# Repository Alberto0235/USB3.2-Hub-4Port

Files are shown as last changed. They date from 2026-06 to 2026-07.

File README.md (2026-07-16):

<h1 align="center">⚡ USB 3.2 Gen 1 — 4-Port Hub</h1>

<p align="center">
High-Speed Hardware Design
</p>

<p align="center">
  
  
  
  
</p>

<p align="center">
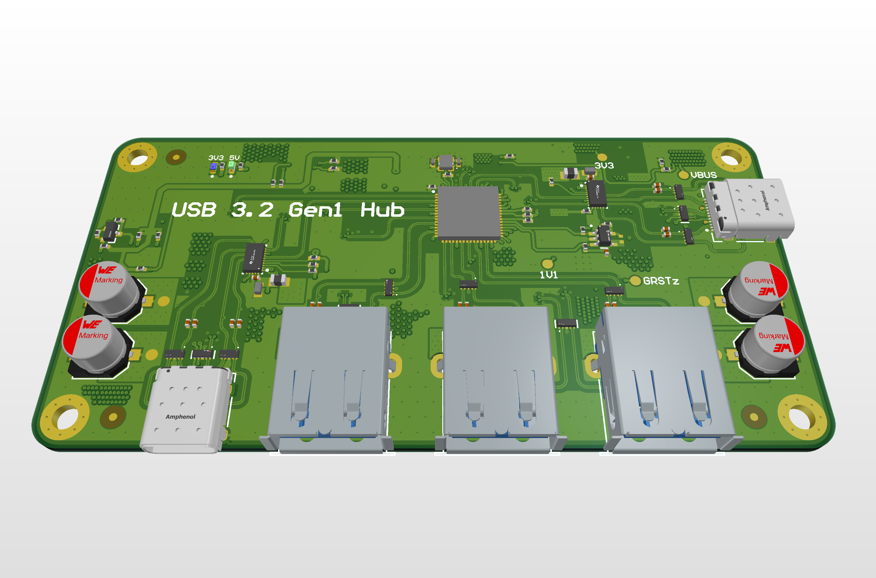
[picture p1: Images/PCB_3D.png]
  
</p>

<p align="center">
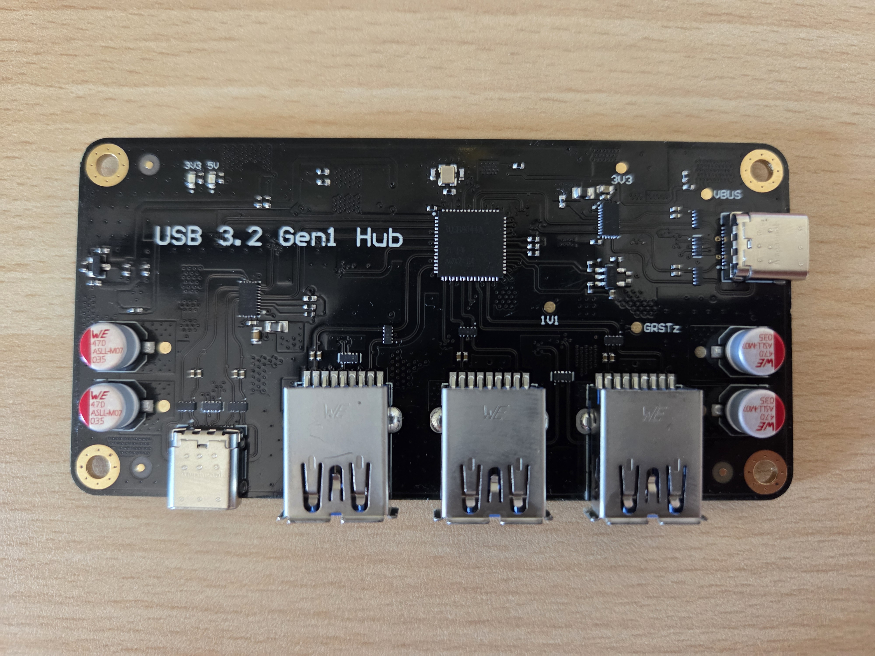
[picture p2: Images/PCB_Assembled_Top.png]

</p>

---

## 🎯 Project Goal

This project started as a question: could I take a commercial-grade USB 3.x system from architecture all the way through to a manufacturable, impedance-controlled 6-layer PCB?

The hub is built around the Texas Instruments **TUSB8044A**, fully bus-powered over USB-C, with one USB-C downstream port (cold-socket compliant) and three USB-A ports, each with independent current limiting. Type-C attach detection, power-up sequencing and overcurrent handling are implemented entirely in hardware, with no microcontroller required.

The areas I specifically wanted to get right:

- Routing 5 Gbps SuperSpeed differential pairs with impedance control
- Understanding the 6-layer stackup advantages
- Implementing USB-C cold socket behavior correctly, in hardware, per spec
- Getting power-up sequencing timing right against the TUSB8044A's datasheet requirements

---

## 🚀 Project Status

- [x] Architecture & component selection
- [x] Schematic capture (hierarchical, multi-sheet)
- [x] Signal integrity analysis & stackup design
- [x] PCB layout & routing
- [x] Manufacturing files (Gerbers, BOM, Pick & Place)
- [x] DFM review (PCBWay)
- [x] PCB fabrication & assembly
- [x] Bring-up & validation

---

## 🧩 Board Features

| Feature | Description |
|---|---|
| ⚡ USB 3.2 Gen 1 | 5 Gbps SuperSpeed, 4-port hub (TUSB8044A) |
| 🔌 USB-C UFP | Bus-powered upstream, 5V/3A max |
| 🧊 Cold Socket | Hardware VBUS gating on USB-C downstream port |
| 🔋 BC1.2 CDP | Charging support on all downstream ports |
| 🛡️ ESD Protection | All USB data lines, CC lines, and VBUS protected |
| 📡 Controlled Impedance | 90Ω differential SS/HS routing, 6-layer stackup |
| 🔄 Power Sequencing | Hardware-controlled, RC-delayed reset |
| 🧠 No MCU | All Type-C and power logic implemented in hardware |

---

## 🏆 Engineering Highlights

### 📡 Signal Integrity — 90Ω Differential Impedance

All SuperSpeed and High-Speed differential pairs are routed exclusively on **L1 and L6**, each directly referenced to a solid, unbroken GND plane (L2 and L5). Routing follows the 5W rule, a minimum of 0.6mm clearance between any differential pair and other signals or copper pour, preventing nearby copper from acting as a parasitic coplanar ground and shifting the impedance off target.

| Parameter | SuperSpeed (USB 3.x) | High-Speed (USB 2.0) |
|---|---|---|
| Target differential impedance | 90Ω ±10% | 90Ω ±10% |
| Intra-pair skew | ≤ 0.15mm (≈1.2ps) | ≤ 3.8mm |
| Max via count per pair | 2 | 4 |
| AC coupling | 100nF, 0402, X7R — TX paths only | — |

<p align="center">
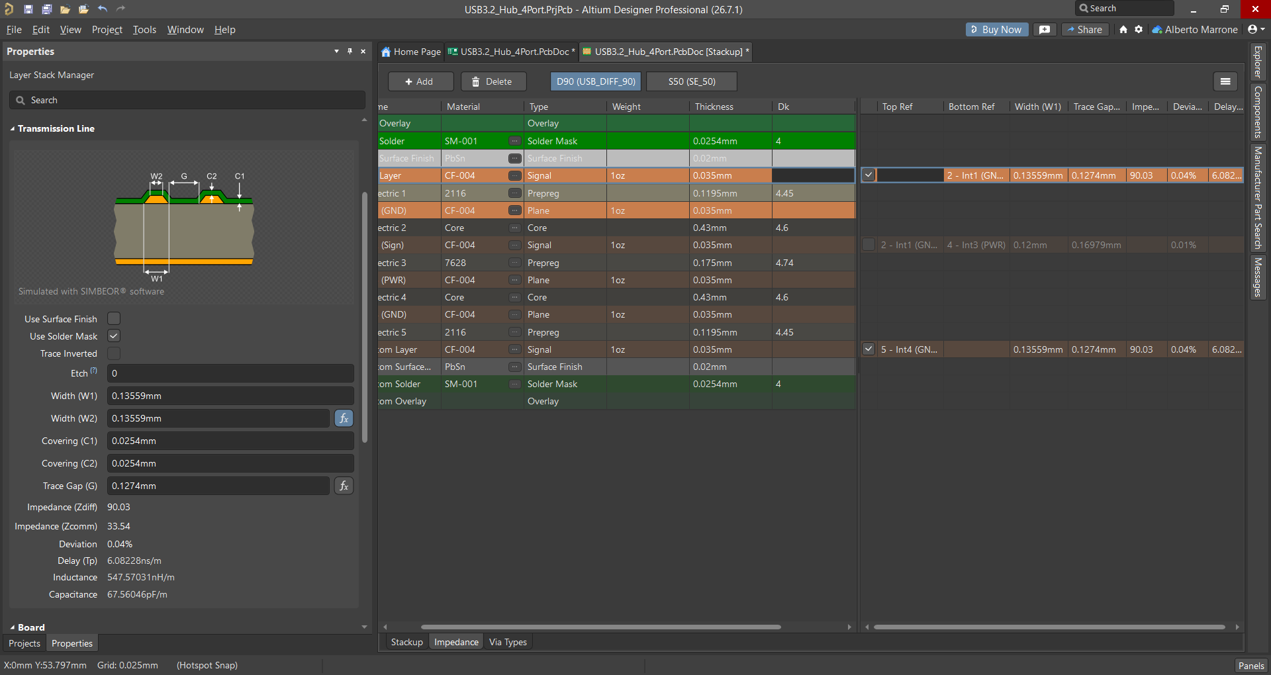
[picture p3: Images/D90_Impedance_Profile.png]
  
</p>

> [!TIP]
> Both the TUSB8044A and HD3SS3220 support **native polarity inversion** on
> SuperSpeed pairs — P/N can be swapped freely during routing with no via
> tricks or register configuration required.

---

### 🧱 6-Layer Stackup Selection

| Layer | Type | Function |
|---|---|---|
| L1 | Signal | High-speed routing & components |
| L2 | GND Plane | Solid reference |
| L3 | Signal | Low-speed control signals |
| L4 | Power Plane | 5V / 3.3V / 1.1V |
| L5 | GND Plane | Solid reference |
| L6 | Signal | High-speed routing & components |

Both signal layers carrying HighSpeed and SuperSpeed traffic (L1 and L6) sit directly against a solid GND plane. Slow control signals are confined to L3, sandwiched between a GND plane (L2) and the power plane (L4), shielding them from both the high-speed layers and external noise.

> [!NOTE]
> The prepreg between L1–L2 and L5–L6 uses **2116 weave** instead of the
> coarser 7628. The finer glass weave reduces the fiber-weave effect,
> keeping the dielectric more homogeneous under the SuperSpeed pairs and
> minimizing intra-pair skew. Full reasoning, including why 6 layers over
> 4, and why an LDO over a second buck for the 1.1V rail, is documented in
> [`Docs/Design_Decisions.md`](Docs/Design_Decisions.md).

---

### 🔌 USB-C Cold Socket Compliance

Per the USB Type-C specification, the downstream USB-C port's VBUS must remain de-energized until a cable is detected, unlike USB-A ports, which are permitted to be hot-socket. This is implemented with a single P-MOSFET acting as a hardware enable gate, requiring no firmware:

- **Source** → PWRCTL1 (TUSB8044A, 3.3V when hub is active)
- **Gate** → ID pin of the downstream HD3SS3220
- **Drain** → EN1 of the TPS2561 power switch

With no cable inserted, the ID pin floats and a 100kΩ gate-source resistor holds the MOSFET off, VBUS stays at 0V. On attach, the HD3SS3220 detects the termination on CC and pulls ID low, turning on the MOSFET and enabling VBUS. The three USB-A ports use direct PWRCTL → EN connections, as hot-socket behavior is permitted there.

---

### 🔋 Power Budget

The hub negotiates 3A from the upstream USB-C port. Hub control circuitry and always-on rails consume a portion of this budget, leaving the remainder for the four downstream ports.

| Item | Current |
|---|---|
| Upstream budget (USB-C UFP) | 3000 mA |
| Hub controller + support circuitry | ≈ 582 mA |
| Available for downstream ports | ≈ 2418 mA |
| Ports 1–2 limit (TPS2561 #1, R_ILIM = 37.4kΩ) | 1.5 A each |
| Ports 3–4 limit (TPS2561 #2, R_ILIM = 56kΩ) | 1.0 A each |
| Sum of all port limits (worst case, all ports active) | 5.0 A |

> [!NOTE]
> The sum of individual port limits (5A) exceeds the available downstream
> budget (2.418A). This is an accepted worst-case scenario: simultaneous
> maximum draw on all four ports is unlikely in practice, and the upstream
> host's own port protection provides a final safeguard if the negotiated
> 3A is exceeded.

---

### ⏱️ Power Sequencing

> [!IMPORTANT]
> The TUSB8044A requires GRSTz to remain asserted for ≥3ms after both VDD
> (1.1V and 3.3V) enter their recommended operating range.

| Event | Time |
|---|---|
| VBUS 5V applied | 0 ms |
| Buck PG asserted → LDO enabled | ≈ 0.5 ms |
| LDO soft-start complete (Css = 2.2nF, tSS ≈ 3.3ms) | ≈ 3.8 ms |
| LDO PG released → RC delay begins | ≈ 4.3 ms |
| GRSTz reaches V_IH → TUSB8044A exits reset | ≈ 16 ms |

The RC delay accounts for the TUSB8044A's internal pull-up on GRSTz (R_int ≈ 14.5–25kΩ): with an external 100kΩ resistor and a 1µF capacitor, R_eq ≈ 12.66kΩ. The time delay is comfortably above the 3ms minimum required after both supplies are stable.

> [!NOTE]
> The measured GRSTz de-assertion delay from VBUS rise to the logic-high threshold is **tGRSTz = 42.6 ms**
> This delay is dominated by the TUSB8044A internal reset release mechanism and the external reset network.
> The measured value confirms that GRSTz remains asserted long enough during power-up sequencing.
> The difference between the expected and measured timing is attributed to device tolerances,
> reset circuitry characteristics and measurement conditions.

<p align="center">
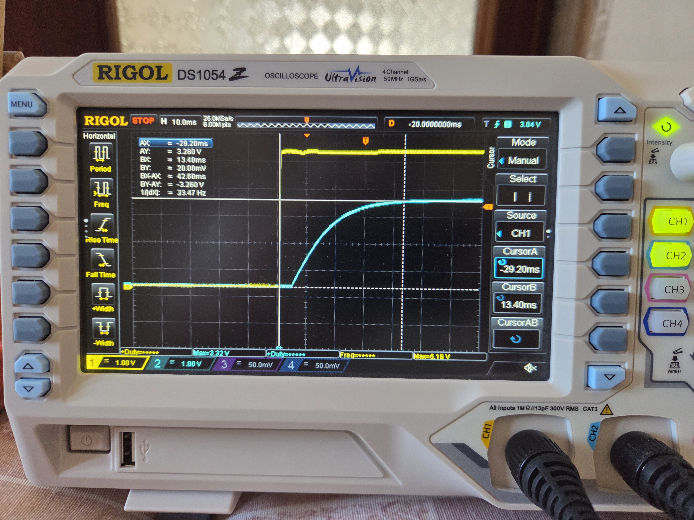
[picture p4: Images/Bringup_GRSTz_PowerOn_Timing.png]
  
</p>
<p align="center"><em>Channel 1 — VBUS 5V.  Channel 2 — GRSTz.  tGRSTz = 42.6 ms from power-on.</em></p>

---

## 🖼️ Design Gallery

### Final Prototype

<p align="center">
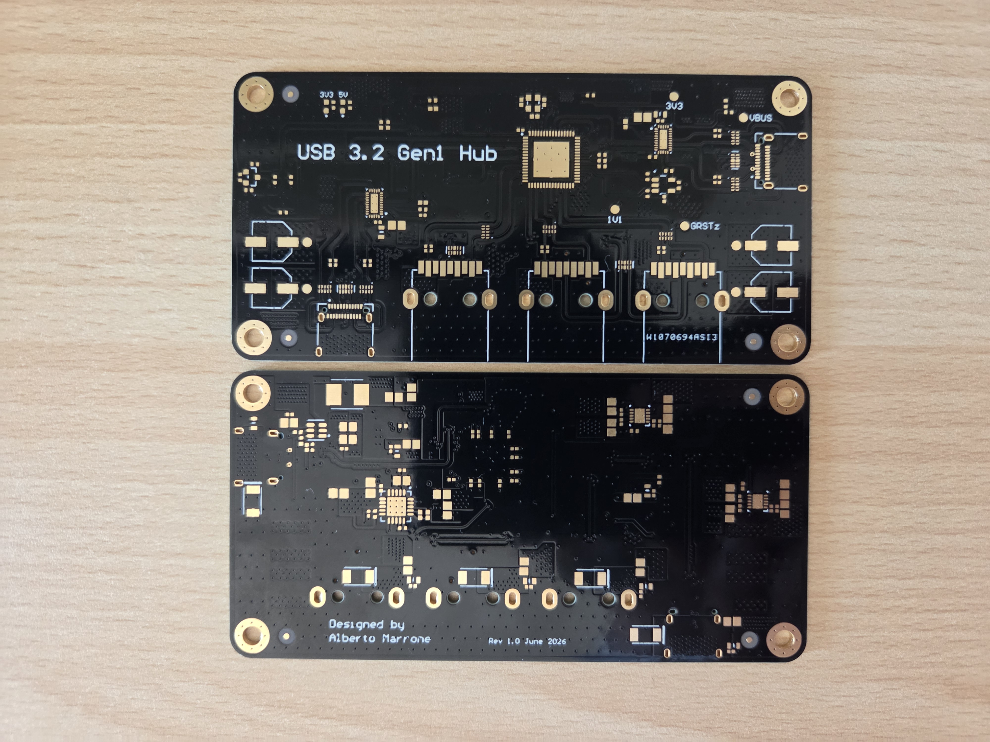
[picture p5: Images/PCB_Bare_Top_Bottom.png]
  
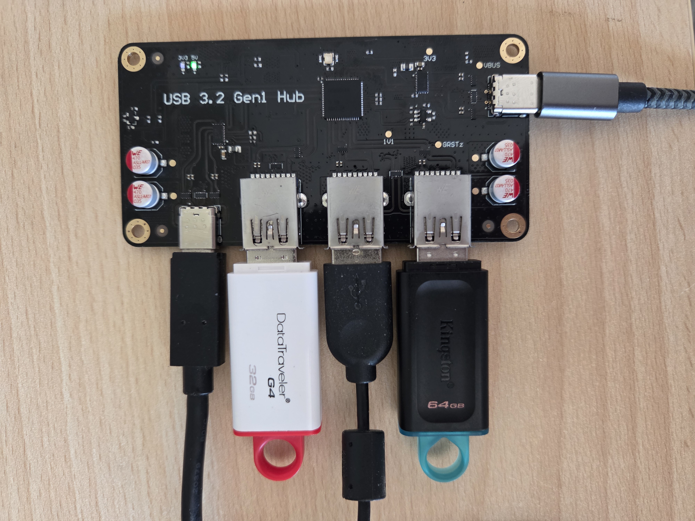
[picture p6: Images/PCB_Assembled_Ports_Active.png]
  
</p>

### PCB Render

<p align="center">
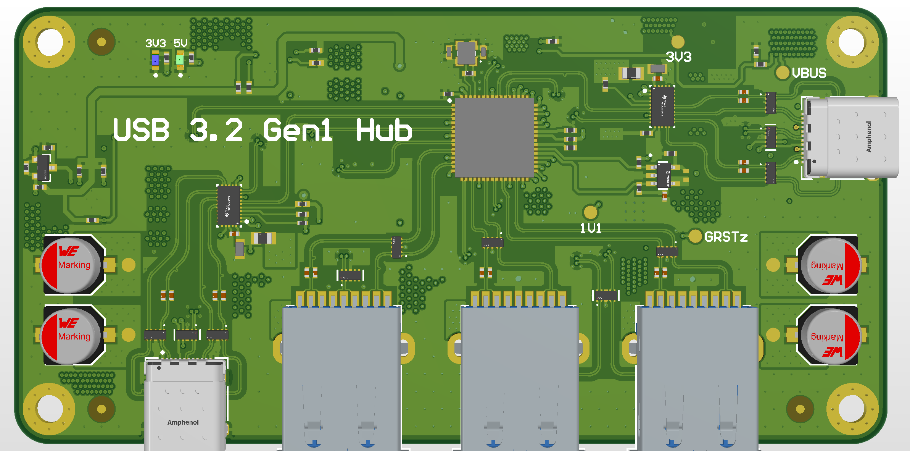
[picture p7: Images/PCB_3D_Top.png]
  
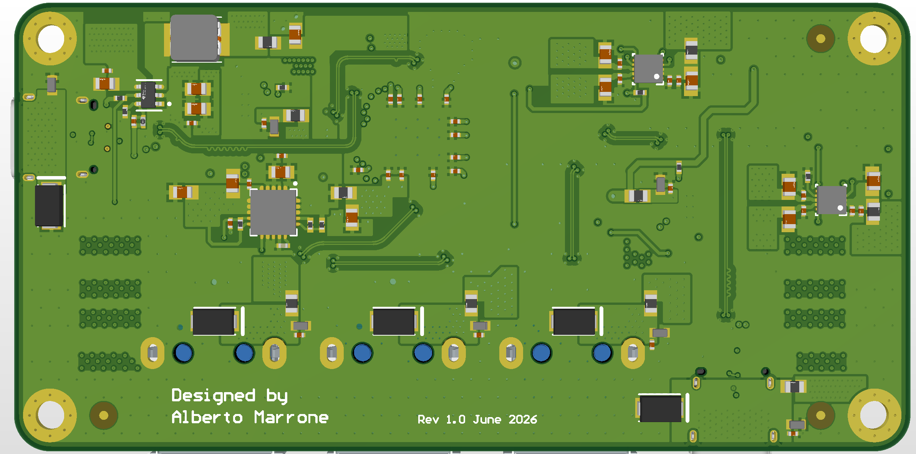
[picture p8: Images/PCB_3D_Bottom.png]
  
</p>

### Schematic Architecture

<p align="center">
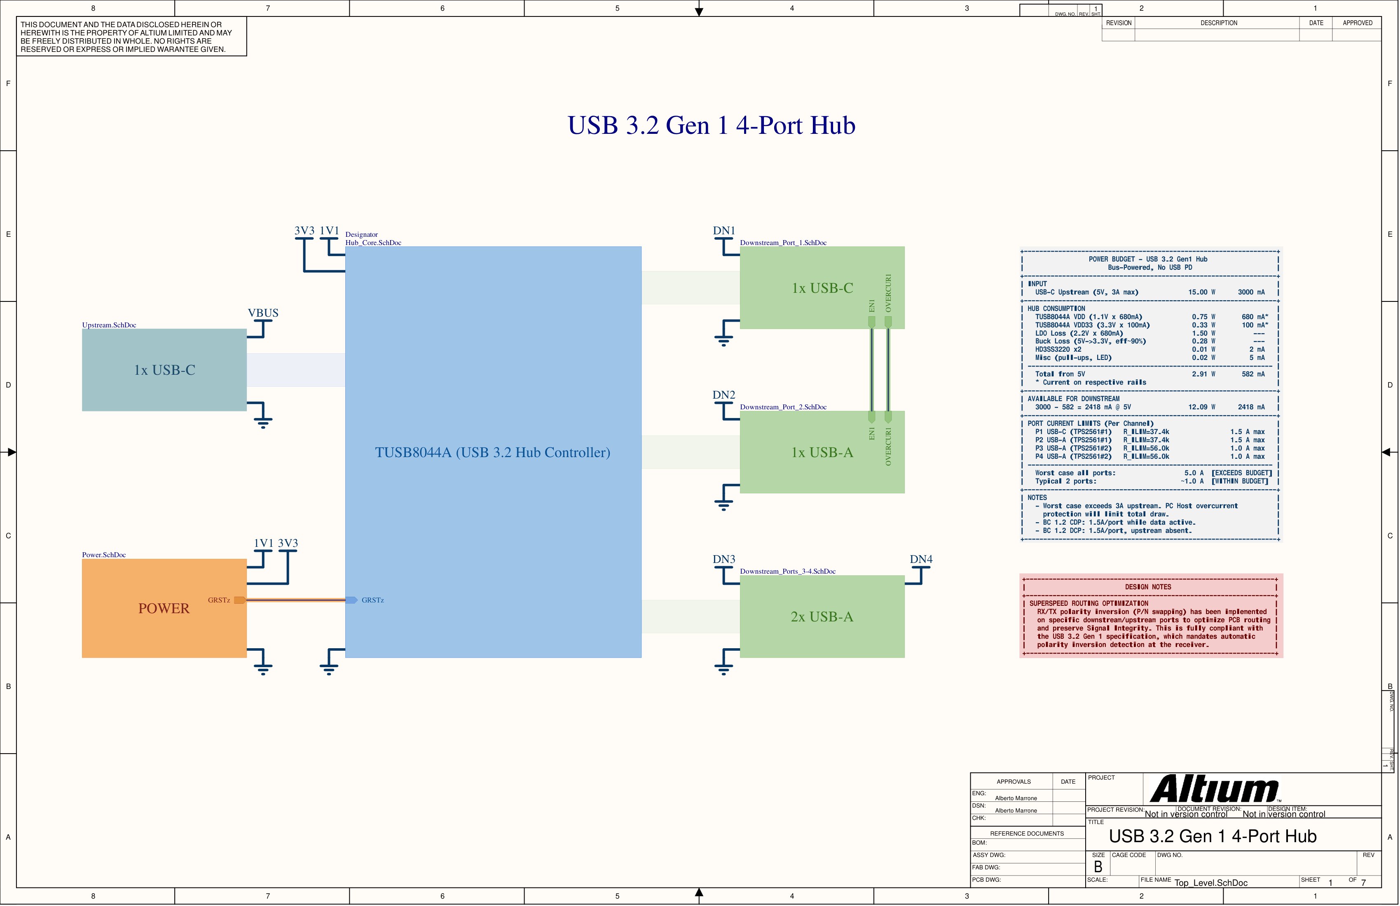
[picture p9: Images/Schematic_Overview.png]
  
</p>

🔗 **Full schematic (PDF, all sheets):** [Schematic_USB_Hub_v1.0.pdf](Hardware/Exports/Schematic_USB_Hub_v1.0.pdf)

### Stackup Development

<p align="center">
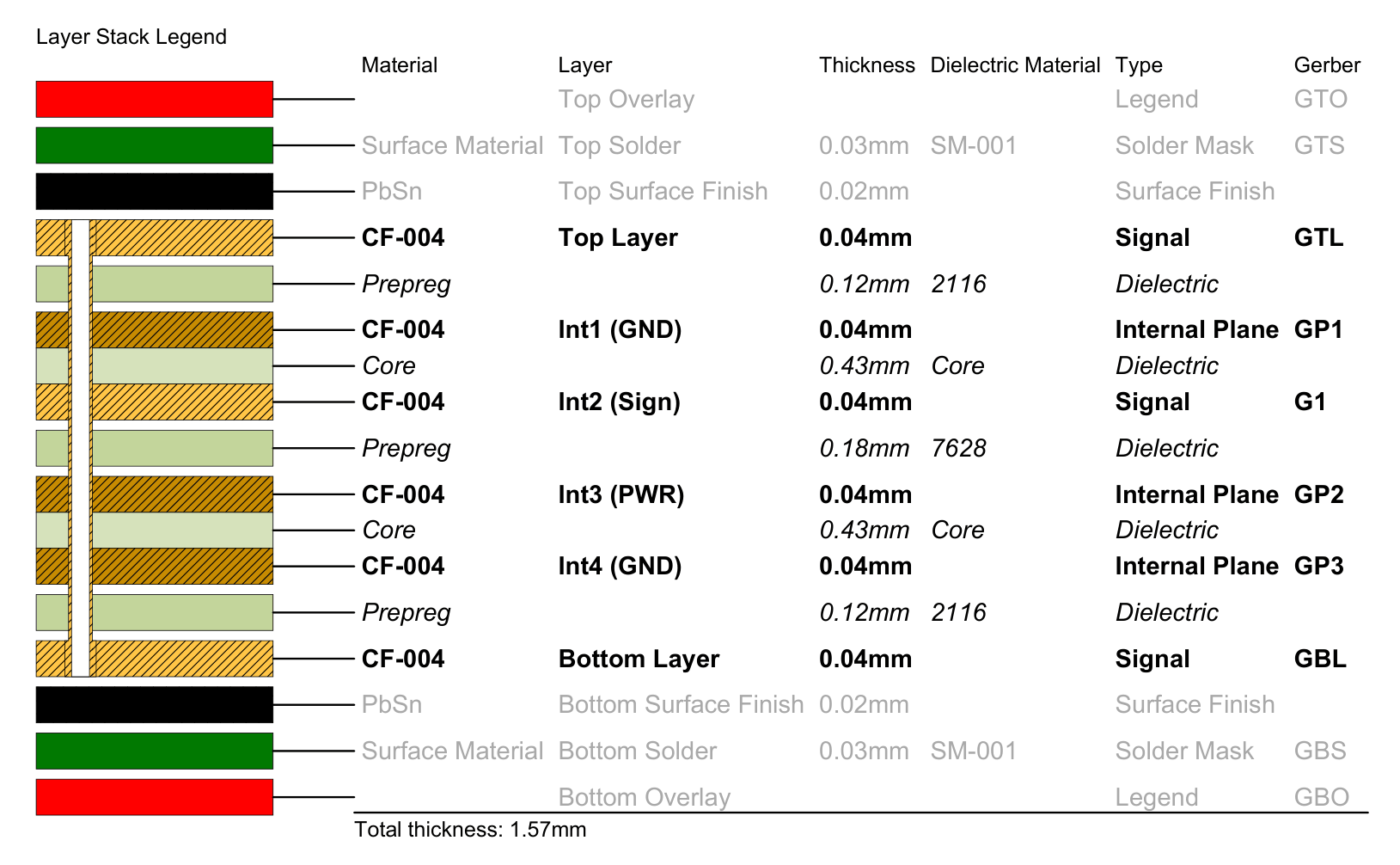
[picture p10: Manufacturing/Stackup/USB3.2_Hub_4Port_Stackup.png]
  
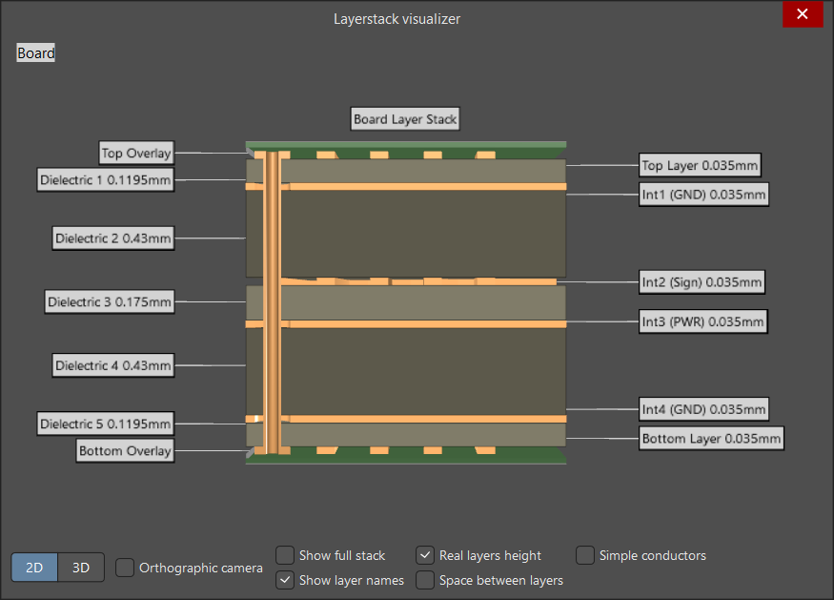
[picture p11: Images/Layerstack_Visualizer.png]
  
</p>

---

## 🔧 Hardware Specifications

| Parameter | Value |
|---|---|
| **Hub Controller** | TUSB8044A — USB 3.2 Gen 1, 5 Gbps, 64-pin VQFN |
| **Upstream Port** | USB-C (UFP/Sink, bus-powered, 5V/3A max) |
| **Downstream Ports** | 1× USB-C (DFP) + 3× USB-A |
| **Type-C Controllers** | 2× HD3SS3220IRNHT (UFP + DFP) |
| **Power Switches** | 2× TPS2561QDRCRQ1 (dual-channel, per-port current limiting) |
| **Power Tree** | 5V → 3.3V (TLV62569PDDCT buck, 2A) → 1.1V (TPS74801RGWRM3 LDO, 1.5A) |
| **Battery Charging** | BC 1.2 CDP enabled on all downstream ports |
| **Cold Socket** | DMG2305UX P-MOSFET on USB-C downstream port |
| **ESD Protection** | PUSB3FR4Z (SS), TPD4E05U06 (USB2.0/CC), SMAJ5.0A (VBUS) |
| **PCB Layers** | 6-layer, impedance-controlled |
| **PCB Finish** | ENIG (Electroless Nickel Immersion Gold) |
| **Copper Weight** | 1 oz outer / 0.5 oz inner |
| **Board Size** | 100 × 50 mm |

---

## 🤝 Manufacturing Partner

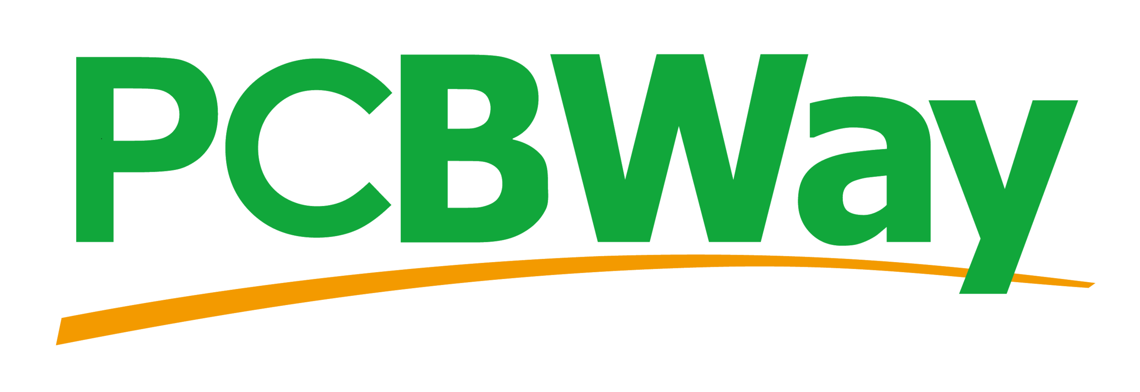
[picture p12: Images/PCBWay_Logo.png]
This prototype was fabricated and assembled by .

The manufacturing process included a standard engineering review prior to production. During this review, the PCBWay engineering team identified a via-in-pad condition that could affect assembly yield. The issue was corrected before fabrication, avoiding an unnecessary prototype revision.

The finished boards met the specified impedance-controlled stackup and assembly requirements. Visual inspection of the assembled prototype showed good component alignment and solder quality, including the 0.5 mm-pitch VQFN packages used by the TUSB8044A and HD3SS3220 devices, with no observable solder bridges or placement defects.

---

## ✅ Bring-Up Results

Validation was performed on the first prototype assembled by PCBWay.
Full procedure and raw measurements are documented in [`Docs/Bringup_Procedure.md`](Docs/Bringup_Procedure.md).

### Power Rails

All rails measured at test points with no downstream load.

| Rail | Target | Measured | Status |
|---|---|---|---|
| VBUS (upstream input) | 5.000 V | 5.018 V | ✅ |
| VDD33 | 3.300 V | 3.325 V | ✅ |
| VDD (1.1V LDO) | 1.100 V | 1.097 V | ✅ |
| GRSTz (at de-assertion) | — | 3.265 V | ✅ |
| VBUS downstream USB-A | 5.000 V | 5.018 V | ✅ |

Idle power consumption (hub only, no downstream devices): **0.02 A @ 5.041 V → 0.1 W.**

### USB Enumeration

Both logical hub interfaces enumerate correctly on the first attempt:

| Interface | PID | Speed | Status |
|---|---|---|---|
| USB 2.0 HS hub | 0x8442 | 480 Mbit/s | ✅ |
| USB 3.x SS hub | 0x8440 | 5 Gbit/s | ✅ |
| HID-to-I2C bridge | 0x82FF | HS | ✅ |

EEPROM custom USB descriptors were successfully programmed and verified after enumeration:

```text
Manufacturer : Alberto Marrone
Product      : USB 3.2 Gen1 4-Port Hub
Serial       : F10100616729  (TI factory UUID)
```

<p align="center">
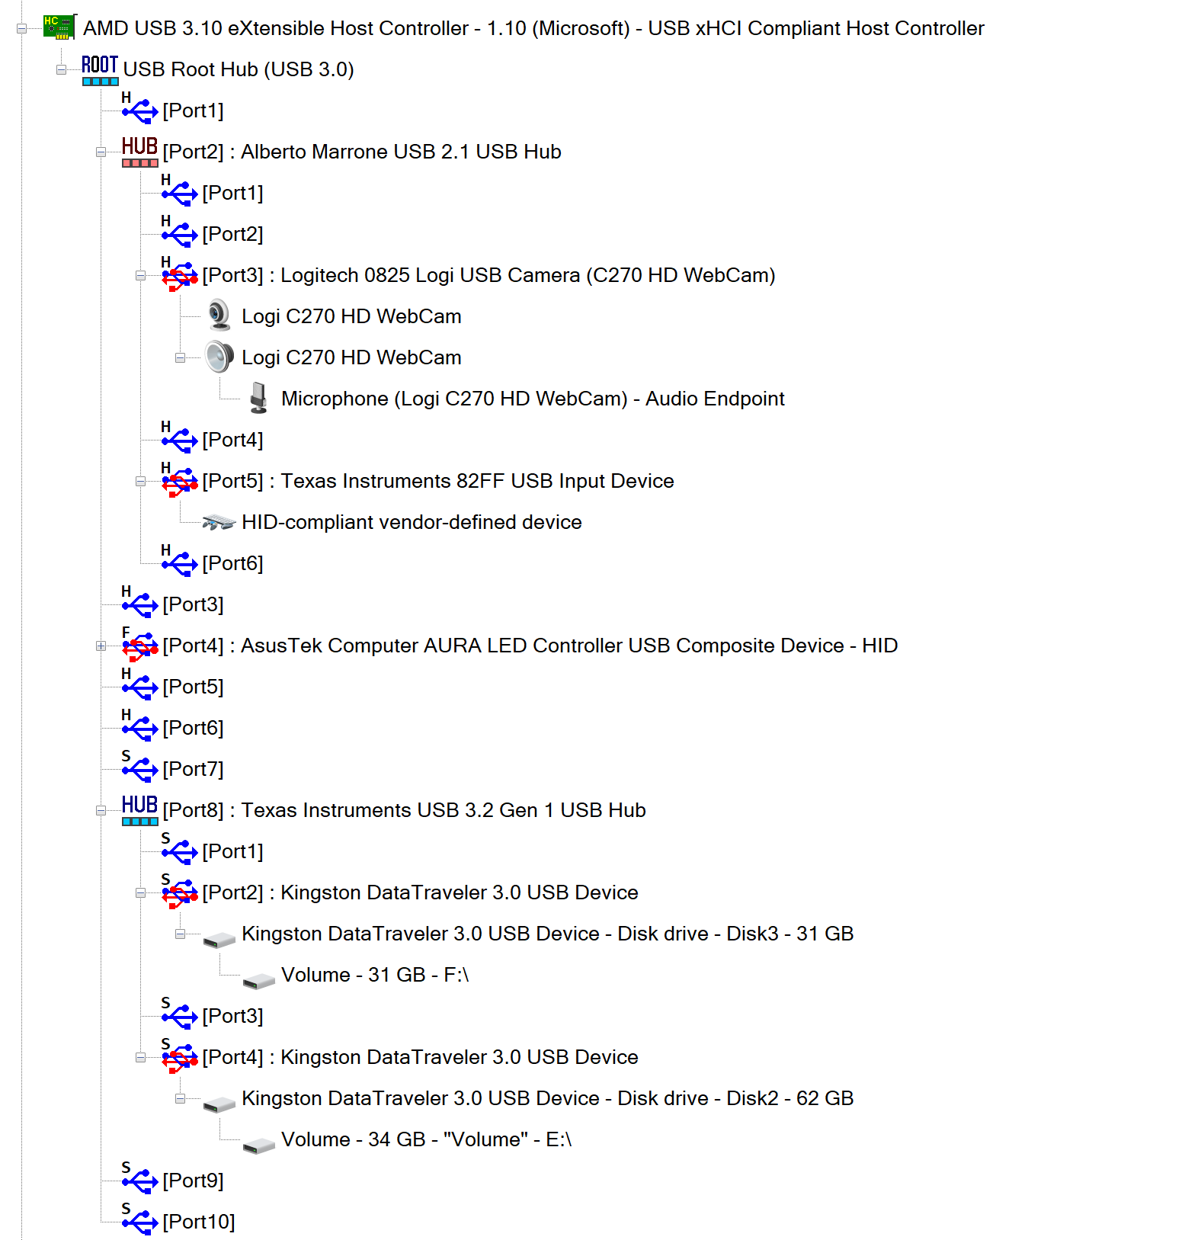
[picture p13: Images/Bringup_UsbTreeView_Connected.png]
  
</p>
<p align="center"><em>UsbTreeView — HS hub and SS hub.</em></p>

### SuperSpeed Performance

Validated using USBDeview's built-in Speed Test utility on a Kingston DataTraveler 3.0 device.

<p align="center">
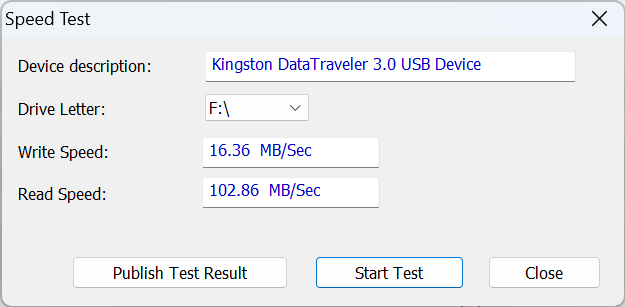
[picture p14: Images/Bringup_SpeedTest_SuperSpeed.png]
  
</p>

Read throughput of 102 MB/s is incompatible with USB 2.0 High-Speed (theoretical max ≈ 40 MB/s), confirming the SuperSpeed (5 Gbit/s) link is established end-to-end.

### Other Tests

- [x] Visual inspection (0.5 mm-pitch QFN solder joints, connectors)
- [x] GRSTz power-on timing (42.6 ms — see [Power Sequencing](#%EF%B8%8F-power-sequencing))
- [x] Per-port functional test — all 4 ports enumeration confirmed
- [x] USB 2.0 device compatibility
- [x] USB 3.0 device compatibility
- [x] Hot-plug on all four ports
- [x] USB-C cold socket — VBUS held at 0 V until cable attach confirmed
- [x] BC1.2 CDP charging verified

> [!NOTE]
> During continuous operation with multiple downstream devices connected, the TUSB8044A hub controller and the HD3SS3220
> controller run warm to the touch. Adding small heatsinks or improving airflow is recommended for prolonged high-load operation.

---

## 🔧 EEPROM Configuration

The TUSB8044A reads a Microchip **24LC08BT-I/OT** EEPROM (8 Kbit, SOT-23) at power-up to load
custom USB descriptors and port configuration. Programming is performed via the chip's internal
**HID-to-I2C bridge** (VID `0x0451`, PID `0x82FF`) — no external programmer required.

Two Python utilities are provided in [`Scripts`](Scripts/):

| Script | Purpose |
|---|---|
| `TUSB8044A_EEPROM_WRITE.py` | Writes the full configuration and verifies every byte before activating |
| `TUSB8044A_EEPROM_READ.py` | Reads all 1024 bytes, prints a register-annotated hex dump, saves a `.bin` |

### Requirements

```bash
pip install hidapi
```

On Windows, run CMD as **Administrator** (required for raw HID access).

### Write — program the hub

Edit the `USER CONFIGURATION` block at the top of `TUSB8044A_EEPROM_WRITE.py`:

```python
MANUFACTURER = "Alberto Marrone"          # manufacturer string (max 32 chars)
PRODUCT      = "USB 3.2 Gen1 4-Port Hub"  # product string (max 32 chars)

VID_HUB      = 0x0451                     # keep TI VID for prototypes
PID_HUB      = 0x8440                     # TUSB8044A SS hub PID

BC12_MASK    = 0x0F                       # BC1.2 CDP enable mask (0x0F = all 4 ports)
```

Then run:

```bash
python TUSB8044A_EEPROM_WRITE.py
```

The 0x55 signature byte that activates the configuration is written only after all registers and strings have been verified. If interrupted, the hub safely falls back to TI factory defaults.

### Read — dump and inspect the EEPROM

```bash
python TUSB8044A_EEPROM_READ.py
```

Outputs a hex dump of Bank 0 (configuration registers + strings), annotates every key
register, decodes the manufacturer/product strings, and saves the full 1024-byte image
to `TUSB8044A_EEPROM.bin` in the working directory.

### Recovery

If the hub shows **"Unknown USB Device"** after a failed write: short EEPROM U6 **pin 3 (SDA)
to pin 2 (GND)** while inserting the USB cable. The TUSB8044A I2C read times out, the hub
boots from TI factory defaults, and the write utility can be re-run.

---

## 📚 Lessons Learned

This project provided practical experience beyond schematic capture and PCB layout, particularly in areas that are rarely covered in university courses:

- Designing and routing a 6-layer controlled-impedance PCB for 5 Gbit/s differential routing.
- Translating impedance targets into manufacturable trace geometries using field-solver calculations.
- Understanding USB Type-C electrical requirements, including cold-socket behavior implemented entirely in hardware.
- Designing reliable power sequencing while accounting for internal IC behavior (such as GRSTz pull-up tolerance), not only the external RC network.
- Developing EEPROM programming and recovery tools through the TUSB8044A HID-to-I²C interface.
- Working through a real manufacturing DFM review with the PCB manufacturer before fabrication.
- Validating the completed hardware through electrical measurements, USB enumeration, and functional testing.

---

## ⬇️ Downloads

| File | Description |
|---|---|
| [Schematic (PDF)](Hardware/Exports/Schematic_USB_Hub_v1.0.pdf) | Full schematic, all sheets |
| [Draftsman Export (PDF)](Hardware/Exports/Draftsman_USB_Hub_v1.0.pdf) | Stackup, layers, 3D views |
| [Gerbers](Manufacturing/Gerbers/Gerber_USB3.2_Hub_4Port_v1.0.zip) | Production-ready Gerber + drill files |
| [BOM](Manufacturing/Assembly/BOM.xlsx) | Bill of materials |
| [Pick & Place](Manufacturing/Assembly/PickPlace.csv) | Assembly placement file |
| [PCBWay Stackup Reference (PDF)](Manufacturing/Stackup/PCBWay_6Layer_Stackup.pdf) | Manufacturer stackup |
| [EEPROM Write Tool](Scripts/TUSB8044A_EEPROM_WRITE.py) | Programs custom USB descriptor strings via HID-to-I2C |
| [EEPROM Read Tool](Scripts/TUSB8044A_EEPROM_READ.py) | Dumps and annotates full EEPROM contents |

---

## 📁 Repository Structure

```text
USB3.2-Hub-4Port/
│
├── Hardware/
│   ├── Altium/
│   │   ├── USB3.2_Hub_4Port.PrjPcb
│   │   ├── USB3.2_Hub_4Port.PcbDoc
│   │   ├── Top_Level.SchDoc
│   │   ├── Hub_Core.SchDoc
│   │   ├── Power.SchDoc
│   │   ├── Upstream.SchDoc
│   │   ├── Downstream_Port_1.SchDoc
│   │   ├── Downstream_Port_2.SchDoc
│   │   ├── Downstream_Port_3-4.SchDoc
│   │   ├── Outputs.OutJob
│   │   ├── USB3.2_Hub_4Port.BomDoc
│   │   ├── USB3.2_Hub_4Port.PCBDwf
│   │   ├── USB3.2_Hub_4Port.PrjPcbVariants
│   │   └── USB3.2_Hub_4Port.PrjPcbStructure
│   │
│   ├── Libraries/
│   │   ├── USB3.2_Hub_4Port.PcbLib
│   │   └── USB3.2_Hub_4Port.SCHLIB
│   │
│   └── Exports/
│       ├── Schematic_USB_Hub_v1.0.pdf
│       └── Draftsman_USB_Hub_v1.0.pdf
│
├── Manufacturing/
│   ├── Gerbers/
│   │   └── Gerber_USB3.2_Hub_4Port_v1.0.zip
│   │
│   ├── Assembly/
│   │   ├── BOM.xlsx
│   │   └── PickPlace.csv
│   │
│   └── Stackup/
│       ├── PCBWay_6Layer_Stackup.pdf
│       └── USB3.2_Hub_4Port_Stackup.png
│
├── Scripts/
│   ├── TUSB8044A_EEPROM_WRITE.py
│   └── TUSB8044A_EEPROM_READ.py
│
├── Docs/
│   ├── Design_Decisions.md
│   └── Bringup_Procedure.md
│
├── Images/               # PCB renders, prototype photos and bring-up measurements
│
└── README.md
```

---

## 📄 License

Released under the MIT License.

You are welcome to study, modify, manufacture, and build upon this design.

---

## 👤 Author

**Alberto Marrone**
MSc Student, Electronics Engineering — Politecnico di Milano
[LinkedIn](https://linkedin.com/in/alberto-marrone-444192274)

*This project is provided for educational and portfolio purposes.*

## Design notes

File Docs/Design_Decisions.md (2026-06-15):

# Design Decisions

## Why a 6-Layer Stackup

The primary design goal was maintaining controlled impedance and continuous return paths for all USB 3.2 Gen 1 SuperSpeed signals.

A conventional 4-layer stackup (Signal / GND / Power / Signal) would force one of the two outer signal layers to reference the power plane. Since the design contains multiple voltage domains (5V, 3.3V, and 1.1V), the power plane requires splits and polygon boundaries that can interrupt high-frequency return currents.

The selected 6-layer stackup allows both outer signal layers to reference solid, uninterrupted ground planes:

* L1 → referenced to L2 (GND)
* L6 → referenced to L5 (GND)

This guarantees a continuous return path for all SuperSpeed and High-Speed USB signals regardless of routing location.

Additional benefits include:

* Improved EMI performance
* Easier impedance control
* Better isolation between high-speed and low-speed signals
* Dedicated internal power distribution layer
* Easier routing

The final stackup is:

| Layer | Function |
| ----- | --- |
| L1 | High-speed signals & components |
| L2 | Solid GND plane |
| L3 | Low-speed control signals |
| L4 | Power distribution |
| L5 | Solid GND plane |
| L6 | High-speed signals & components |

---

## Why 2116 Prepreg for the Outer High-Speed Layers

The impedance-controlled USB pairs are routed exclusively on the outer layers (L1 and L6).

Between these layers the 2116 prepreg was selected instead of the coarser 7628 weave.

Compared to 7628, 2116 provides:

* A more homogeneous dielectric environment
* Reduced fiber-weave induced skew
* Thinner dielectric spacing
* More practical trace geometries for USB routing

The thinner dielectric also reduces the trace width required to achieve 90Ω differential impedance.

Using the selected stackup:

* Dielectric thickness = 0.12mm
* Differential impedance target = 90Ω
* Resulting geometry for the Diff pairs = 0.136mm trace width / 0.127mm gap

These dimensions allow straightforward breakout from the TUSB8044A and HD3SS3220 without excessive layer transitions.

The internal dielectric layers continue to use standard materials where signal integrity requirements are less critical.

---

## Why an LDO for the 1.1V Core Rail

The TUSB8044A requires a dedicated 1.1V rail for its internal core and PLL circuitry.

Two approaches were evaluated:

1. Secondary buck converter
2. Linear regulator

A buck converter would improve efficiency but introduce switching ripple and high-frequency noise directly onto the PLL supply.

The selected TPS74801 LDO provides:

* Low output noise
* High PSRR
* Simplified sequencing
* Reduced risk of PLL-related stability issues

Thermal analysis showed the additional dissipation remains acceptable within the expected operating conditions.

This approach is also consistent with Texas Instruments reference implementations for the TUSB8044A family.

---

## Why HD3SS3220 for USB-C Control

The TUSB8044A manages the USB hub functionality but does not provide USB Type-C attach detection or SuperSpeed orientation management.

The HD3SS3220 was selected because it combines:

* USB Type-C CC controller
* Orientation detection
* SuperSpeed lane switching
* Current advertisement logic

This keeps the design fully hardware-controlled while maintaining compliance with USB Type-C requirements.

---

## Why USB-C Cold Socket Implementation

USB Type-C ports must not present VBUS until a valid attachment has been detected through the CC pins. To satisfy this requirement, the downstream USB-C port uses a hardware-controlled enable path:

HD3SS3220 → PMOS → TPS2561 Enable

When no cable is present:

* CC detection remains inactive
* The PMOS remains off
* VBUS is disconnected

Once a valid attachment is detected:

* The HD3SS3220 asserts its ID output
* The PMOS turns on
* The TPS2561 power switch is enabled
* VBUS becomes available at the connector

No firmware is required.

The three USB-A ports remain permanently powered because USB-A connectors are allowed to operate as hot-socket ports.

---

## Why Copper Clearance Matters

High-speed differential pairs were routed with a minimum clearance of approximately 0.6mm from surrounding copper features. The objective is to prevent nearby copper from acting as an unintended coplanar reference plane and avoid crosstalk.

If copper is placed too close to a microstrip pair:

* Effective impedance decreases
* Field distribution changes
* Differential impedance may deviate from the target value
* Crosstalk

The selected clearance follows the 5W guideline and keeps impedance variation negligible compared to manufacturing tolerances. This spacing was applied consistently around all HighSpeed and SuperSpeed differential pairs throughout the design.

---

## Why a Hardware-Only Architecture

A design goal from the beginning was eliminating unnecessary firmware. Functions often delegated to a microcontroller are instead handled through dedicated hardware:

* USB-C attach detection
* Orientation detection
* Power sequencing
* Current limiting
* Overcurrent reporting
* Reset timing

Advantages include:

* Reduced system complexity
* Faster startup
* No firmware maintenance
* Lower validation effort
* Fewer failure modes

The final design contains no MCU and requires no software for normal operation.

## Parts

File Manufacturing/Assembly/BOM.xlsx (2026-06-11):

Name | Description | Designator | Quantity | Manufacturer 1 | Manufacturer Part Number 1 | Supplier 1 | Supplier Part Number 1 | Footprint
GRM21BZ71E106KE15L | Chip Multilayer Ceramic Capacitors for General Purpose, 0805, 10uF, X7R, 15%, 10%, 25V | C1, C11, C13, C14, C16, C24, C63, C65, C76, C78 | 10 | Murata | GRM21BZ71E106KE15L | Arrow Electronics | GRM21BZ71E106KE15L | FP-GRM21B-0_2-e0_2_0_7-IPC_B
GRT155R71H104KE01J | Multi-Layer Ceramic Capacitor 100nF 50V X7R ±10% 0402 Paper T/R | C2, C3, C4, C5, C6, C7, C8, C9, C12, C15, C17, C18, C19, C20, C23, C25, C30, C32, C33, C34, C35, C36, C39, C41, C43, C44, C46, C47, C48, C49, C51, C52, C53, C55, C56, C57, C59, C60, C64, C66, C68, C69, C70, C72, C73, C77, C79 | 47 | Murata | GRT155R71H104KE01J | Mouser | 81-GRT155R71H104KE1J | FP-GRT155-0_05-IPC_C
GCM1555C1H6R8BA16J | Ceramic Capacitor for Automotive 6.8pF ±0.1pF 50VDC C0G 0402 Paper T/R | C10 | 1 | Murata | GCM1555C1H6R8BA16J | Mouser | 81-GCM1555C1H6R8BA6J | FP-GCM155-0_05-IPC_B
GRM21BZ7YA475KE15K | Chip Multilayer Ceramic Capacitors for General Purpose, 0805, 4.7uF, X7R, 15%, 10%, 35V | C21, C22, C58, C71 | 4 | Murata | GRM21BZ7YA475KE15K | Newark | GRM21BZ7YA475KE15K | FP-GRM21B-0_2-e0_2_0_7-IPC_A
AC0402KRX7R9BB222 | CAP CER 2200PF 50V X7R 0402 | C26 | 1 | Yageo Group | AC0402KRX7R9BB222 | DigiKey | 311-3072-1-ND | FP-AC0402-0_5-MFG
GRM155Z71A105KE01D | Chip Multilayer Ceramic Capacitors for General Purpose, 0402, 1.0uF, X7R, 15%, 10%, 10V | C27 | 1 | Murata | GRM155Z71A105KE01D | Mouser | 81-GRM155Z71A105KE1D | FP-GRM155-0_1-IPC_C
1u | The superior mechanical strength and reliability due to the monolithic structure. Low ESR, ESL and excellent frequency characteristics allow for a circuit design that closely conforms to theoretical values. Low self-heating and high ripple resistance due to low ESR. No polarity | C28, C29, C31, C40, C42, C45, C50, C54, C67 | 9 | TDK | C1608X7R1H105K080AB | Mouser | 810-C1608X7R1H105K08 | CAPC1608X90N
15pF | AVX - 04025U150FAT2A - CAP, MLCC, C0G / NP0, 15PF, 50V, 0402 | C37, C38 | 2 | KYOCERA AVX | 04025U150FAT2A | Arrow Electronics | 04025U150FAT2A | CAPC1005X56N
865060543005 | Alum. Electrolytic Cap 47UF 35V 5.5MMV-CHIP Wcap-asll, Lifetime 2000H +105OC | C61, C62, C74, C75 | 4 | Wurth Elektronik | 865060543005 | DigiKey | 732-8585-6-ND | WCAP-ASLL_D6.3H5.5
LTST-C190KGKT | LED GREEN CLEAR CHIP SMD | D1 | 1 | Lite-On | LTST-C193TGKT-5A | DigiKey | 160-1832-1-ND | FP-LTST-C190KGKT-MFG
LTST-C193TBKT-5A | LED BLUE CLEAR CHIP SMD | D2 | 1 | Diodes Inc. | LTST-C193TBKT-5A | Mouser | 859-LTSTC193TBKT5A | FP-LTST-C193TBKT-5A-MFG
SMAJ5.0A | SMAJ Transient Voltage Suppressor Diode Series, 3.5 V, -55 to 150 degC, 2-Pin SMA, RoHS, Tape and Reel | D3, D7, D10, D12, D14 | 5 | Bourns | SMAJ5.0A | Avnet | 67R1573 | BOUR-SMA-2_V
PUSB3FR4Z | TVS DIODE 3.3VWM 3VC DFN2510A-10 | D4, D5, D6, D8, D9, D11, D13 | 7 | Nexperia | PUSB3FR4Z | Mouser | 771-PUSB3FR4Z | FP-SOT1176-1-MFG
BLM21PG221SN1D | Chip Ferrite Bead, 0805, 220Ω @ 100MHz, 0.045Ω, 25%, 2A | FB1, FB2, FB3, FB4, FB5, FB6, FB7, FB8, FB9, FB10, FB11, FB12 | 12 | Murata | BLM21PG221SN1D | Mouser | 81-BLM21P221SG | FP-BLM21-0_2-t0_85-e0_5-IPC_B
12401610E4#2A | CONN RCP USB3.1 TYPEC 24P SMD RA | J1, J2 | 2 | Amphenol | 12401610E4#2A | Arrow Electronics | 12401610E4#2A | FP-12401610E4#2A-MFG
692122030100 | Conn USB 3.0 Type A RCP 9 POS 1.25mm Solder RA SMD 9 Terminal 1 Port T/R | J3, J4, J5 | 3 | Wurth Elektronik | 692122030100 | Mouser | 710-692122030100 | 692122030100
2.2uH | SMD Power Choke Coil SMD 5x5 2.2uH | L1 | 1 | Panasonic | ETQ-P3M2R2HFP | Mouser | 667-ETQ-P3M2R2HFP | IND_ETQP3M3R3YFP
DMG2305UX-13 | MOSFET P-CH 20V 4.2A SOT23 | Q1 | 1 | Diodes Inc. | DMG2305UX-13 | Arrow Electronics | DMG2305UX-13 | FP-SOT23-MFG
ERJ-2RKF4533X | RES 453KΩ ±1% 0.100W 0402 | R1 | 1 | Panasonic | ERJ-2RKF4533X | Arrow Electronics | ERJ-2RKF4533X | FP-ERJ2RK-MFG
AC0402FR-7W100KL | RES 100kΩ ±1% 0.125W 0402 | R2, R3, R4, R5, R6, R30, R31 | 7 | Yageo Group | AC0402FR-7W100KL | Mouser | 603-AC0402FR-7W100KL | FP-AC0402-MFG
AC0402FR-071K87L | RES 1.87kΩ ±1% 0.063W 0402 | R7 | 1 | Yageo Group | AC0402FR-071K87L | Mouser | 603-AC0402FR-071K87L | FP-AC0402-IPC_A
AC0402FR-7W4K99L | RES 4.99kΩ ±1% 0.125W 0402 | R8 | 1 | Yageo Group | AC0402FR-7W4K99L | Mouser | 603-AC0402FR-7W4K99L | FP-AC0402-IPC_A
AC0402FR-0790K9L | RES 90.9kΩ ±1% 0.063W 0402 | R9 | 1 | Yageo Group | AC0402FR-0790K9L | Mouser | 603-AC0402FR-0790K9L | FP-AC0402-MFG
AC0402FR-0710KL | RES 10kΩ ±1% 0.063W 0402 | R10, R16, R17, R19, R21, R23, R28, R29, R32, R33, R34, R35, R37, R38 | 14 | Yageo Group | AC0402FR-0710KL | Mouser | 603-AC0402FR-0710KL | FP-AC0402-MFG
AC0402FR-07200KL | RES 200kΩ ±1% 0.063W 0402 | R11, R24 | 2 | Yageo Group | AC0402FR-07200KL | Mouser | 603-AC0402FR-07200KL | FP-AC0402-MFG
AC0402FR-134K7L | RES 4.7kΩ ±1% 0.063W 0402 | R12, R14, R15, R25 | 4 | Yageo Group | AC0402FR-134K7L | Avnet | 49AK0445 | FP-AC0402-MFG
AC0402FR-07909KL | RES 909kΩ ±1% 0.063W 0402 | R13, R26 | 2 | Yageo Group | AC0402FR-07909KL | Mouser | 603-AC0402FR-07909KL | FP-AC0402-IPC_A
AC0402FR-079K53L | RES 9.53kΩ ±1% 0.063W 0402 | R18 | 1 | Yageo Group | AC0402FR-079K53L | Avnet | 49AK0431 | FP-AC0402-IPC_C
AC0402FR-071ML | RES 1MΩ ±1% 0.063W 0402 | R20 | 1 | Yageo Group | AC0402FR-071ML | DigiKey | YAG3450DKR-ND | FP-AC0402-IPC_A
AC0402FR-07499KL | RES 499kΩ ±1% 0.063W 0402 | R27 | 1 | Yageo Group | AC0402FR-07499KL | Mouser | 603-AC0402FR-07499KL | FP-AC0402-IPC_C
AC0402FR-0756KL | RES 56kΩ ±1% 0.063W 0402 | R36 | 1 | Yageo Group | AC0402FR-0756KL | Arrow Electronics | AC0402FR-0756KL | FP-AC0402-IPC_A
AC0402FR-0737K4L | RES 37.4kΩ ±1% 0.063W 0402 | R39 | 1 | Yageo Group | AC0402FR-0737K4L | Mouser | 603-AC0402FR-0737K4L | FP-AC0402-IPC_B
TLV62569PDDCT | IC REG BUCK ADJ 2A TSOT23-6 | U1 | 1 | Texas Instruments | TLV62569PDDCT | DigiKey | 296-47088-1-ND | FP-DDC0006A-IPC_C
TPS74801RGWTG4 | Single Output LDO, 1.5 A, Adjustable 0.8 to 3.6 V Output, 0.8 to 5.5 V Input, with Programmable Soft Start, 20-pin VQFN (RGW), -40 to 125 degC, Green (RoHS & no Sb/Br) | U2 | 1 | Texas Instruments | TPS74801RGWTG4 | Mouser | 595-TPS74801RGWTG4 | TI-RGW20-3150X3150TP_V
TUSB8044ARGCR | Four-port USB 3.2 x1 Gen1 hub with USB billboard | U3 | 1 | Texas Instruments | TUSB8044ARGCR | Mouser | 595-TUSB8044ARGCR | QFN50P900X900X100-65N-D
TPD4E05U06QDQARQ1 | TVS DIODE 5.5V 14V 10USON | U4, U8, U10, U11 | 4 | Texas Instruments | TPD4E05U06QDQARQ1 | Arrow Electronics | TPD4E05U06QDQARQ1 | FP-DQA0010A-MFG
HD3SS3220IRNHT | USB TYPE-C DRP PORT CONTROLLER W | U5, U7 | 2 | Texas Instruments | HD3SS3220IRNHT | Arrow Electronics | HD3SS3220IRNHT | FP-RNH0030A-MFG
24LC08BT-I/OT | IC EEPROM 8K I2C 400KHZ SOT23-5 | U6 | 1 | Microchip | 24LC08BT-I/OT | Arrow Electronics | 24LC08BT-I/OT | FP-C04-091-OT-MFG
TPS2561QDRCRQ1 | Automotive Catalog Dual Channel Precision Adjustable Current-Limited Power Switch, 0.25 to 2.5 A Current Limit, -40 to 125 degC, 10-pin SON (DRC), Green (RoHS & no Sb/Br) | U9, U12 | 2 | Texas Instruments | TPS2561QDRCRQ1 | Mouser | 595-TPS2561QDRCRQ1 | DRC0010A_V
24MHz | 24 MHz +/-10ppm Crystal 10pF 50 Ohms 4-SMD, No Lead , -20C ~ 70C | X1 | 1 | Abracon | ABM10N-24.0000MHZ-10-B1U-T3 | Farnell | ABM10N-24.0000MHZ-10-B1U-T3 | ABM10N240000MHZ10B1UT3

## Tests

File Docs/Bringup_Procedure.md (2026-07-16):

# Bring-Up Procedure

## Prerequisites

- Multimeter
- Oscilloscope (recommended) or logic probe
- Power resistors for overcurrent test — see Step 6
- USB-C cable and host PC
- USB 3.0 flash drive (for per-port test)

---

## Step 1 — Visual Inspection

Check for solder bridges and cold joints on the TUSB8044A (0.5mm-pitch VQFN), the two HD3SS3220 (0.5mm-pitch VQFN), the TPS2561 switches, and all connector pads.

---

## Step 2 — Power-On (No USB Connection)

Do not connect USB yet. Apply a current-limited 5V supply to the VBUS test point and measure:

- TP3 (5V_VBUS): 5.0V ±5%
- TP4 (3V3_VDD): 3.3V ±3%
- TP5 (1V1_VDD): 1.1V ±3%

If any rail is missing, check the corresponding regulator before proceeding.

---

## Step 3 — GRSTz Timing (Oscilloscope)

Verify that GRSTz remains asserted during power-up and de-asserts only after all supply rails have stabilized. On the prototype board, the measured delay from VBUS application to GRSTz reaching 3.28V was 42.6ms.

---

## Step 4 — USB Enumeration

Connect to a USB 3.x capable host. The hub should enumerate with the VID:PID programmed into the EEPROM (see Known Configuration below). Check Device Manager (Windows) or run `lsusb -v` (Linux) for both the SS and HS hub interfaces.

---

## Step 5 — Per-Port Functional Test

Connect a USB 3.0 flash drive to each port in sequence. Verify the drive is recognized at SuperSpeed link rate and that data transfer works correctly. 

---

## Step 6 — Overcurrent Test

> [!WARNING]
> This test dissipates several watts in a resistor. Use a resistor rated
> well above the calculated power, mount it on a heatsink or non-flammable
> surface, and limit test duration to avoid overheating components.

Rather than shorting VBUS directly, load each port with a resistor sized to exceed the TPS2561's configured current limit:

| Ports | R_ILIM | I_LIM (max, per datasheet) | Test Load Target | Resistor | Power Dissipated |
|---|---|---|---|---|---|
| 1–2 (TPS2561 #1) | 37.4kΩ | ≈ 1.64A | ≈ 2.0A | 2.5Ω | ≈ 10W |
| 3–4 (TPS2561 #2) | 56kΩ | ≈ 1.09A | ≈ 1.4A | 3.6Ω | ≈ 7W |

Procedure:

1. With the port powered and no other load attached, connect the test resistor across VBUS and GND on that port.
2. Probe the corresponding FAULTx pin (TPS2561) or OVERCURz pin (TUSB8044A) — it should assert when the load current exceeds the configured limit.
3. Remove the resistor and verify the FAULTx/OVERCURz signal deasserts and the port returns to normal operation, matching the behavior described in the TPS2561 datasheet.

---

## Step 7 — EEPROM Verification

With the hub enumerated, run the read utility to confirm the configuration is loaded correctly:

```bash
python Scripts/TUSB8044A_EEPROM_READ.py
```

Expected output: Signature `0x55`, Manufacturer `Alberto Marrone`, Product `USB 3.2 Gen1 4-Port Hub`.

---

## Test Conditions (Rev A)

- No USB PD — 5V only, max 3A negotiated from upstream
- Billboard disabled (no USB-C Alternate Mode implemented)
- Idle power consumption: 0.02 A @ 5.041 V (100 mW)
- GRSTz measured de-assertion

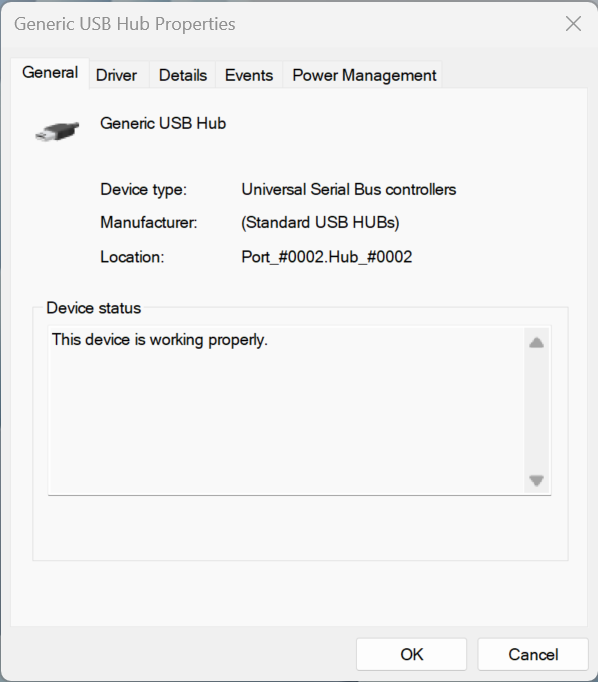
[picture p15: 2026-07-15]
Images/Bringup_DevMgr_HS_Hub_Properties.png

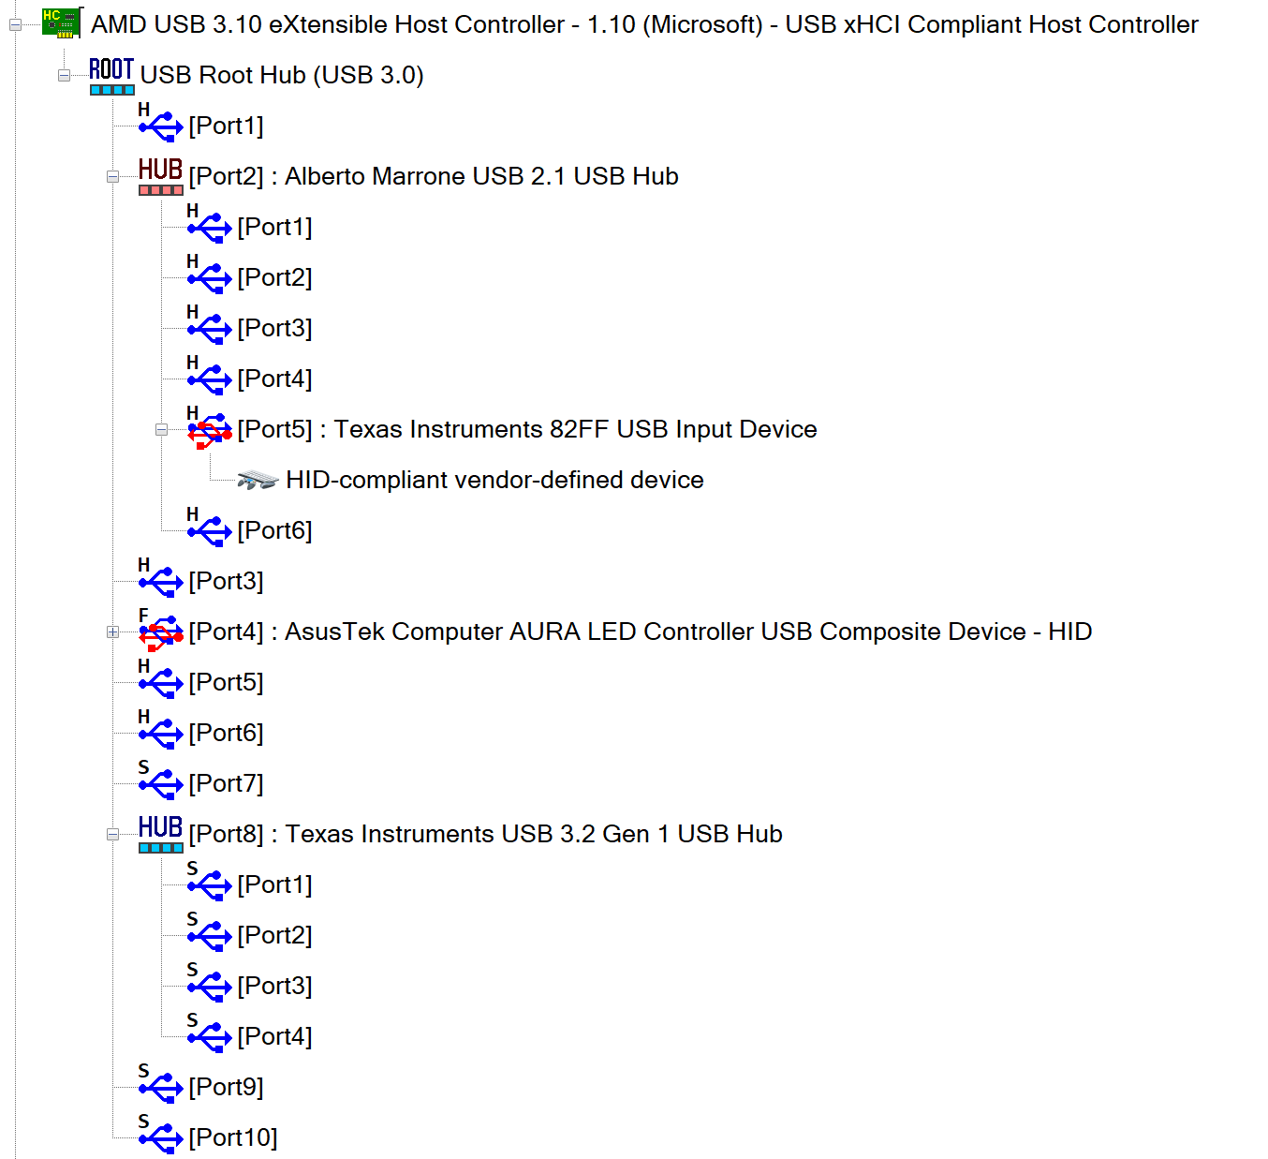
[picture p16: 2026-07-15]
Images/Bringup_UsbTreeView_Idle.png

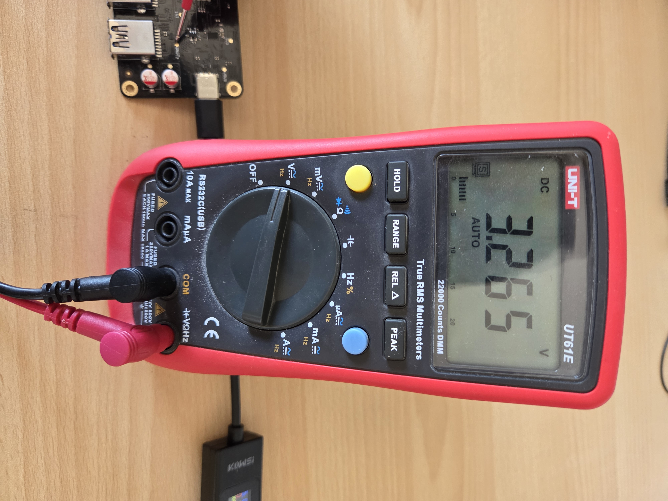
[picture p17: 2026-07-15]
Images/Bringup_TP_GRSTz.png

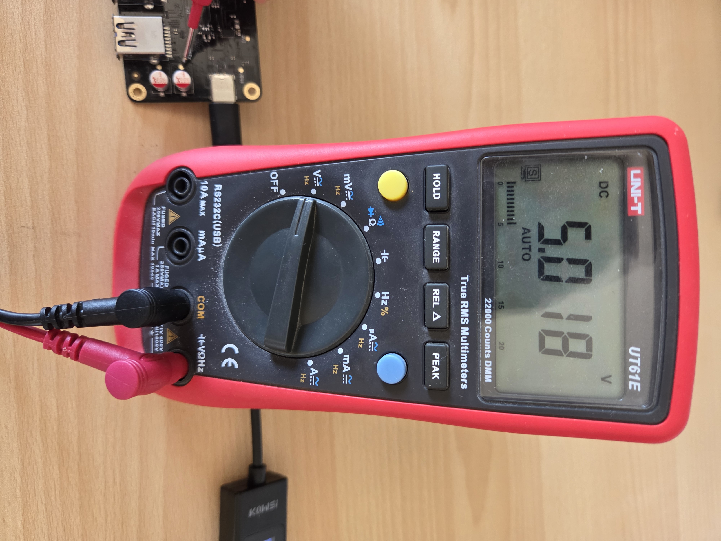
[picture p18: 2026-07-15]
Images/Bringup_TP_VBUS_Downstream.png

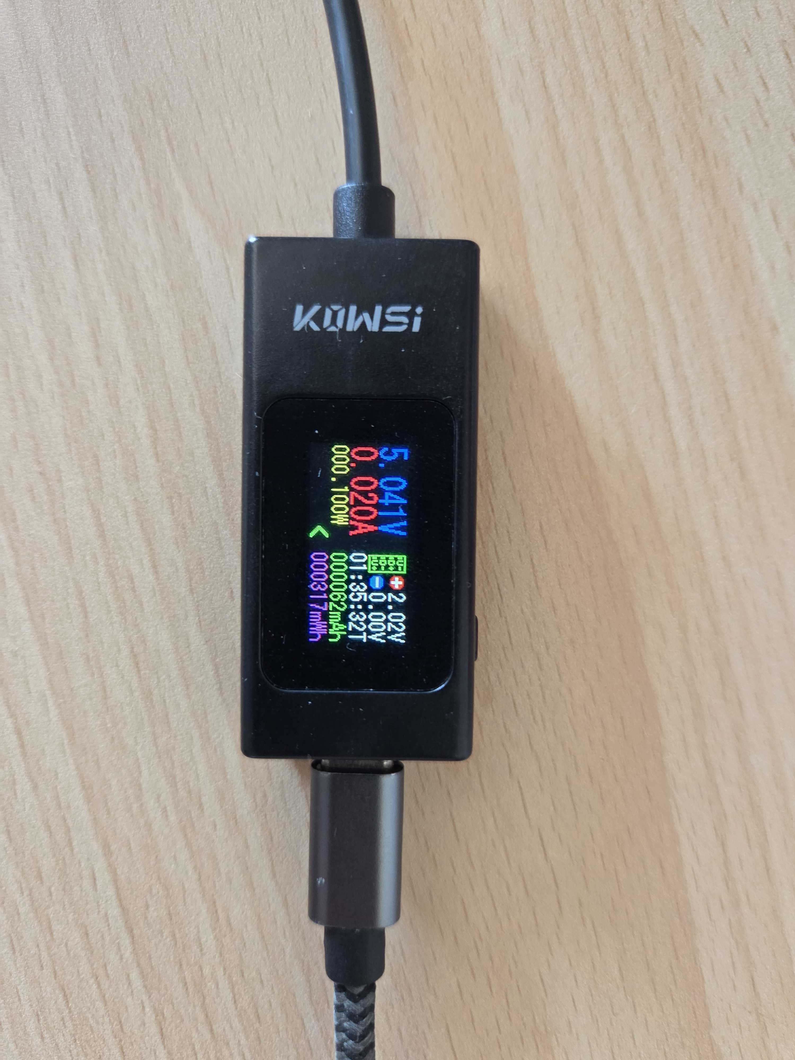
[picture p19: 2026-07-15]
Images/Bringup_PowerMeter_Idle.png

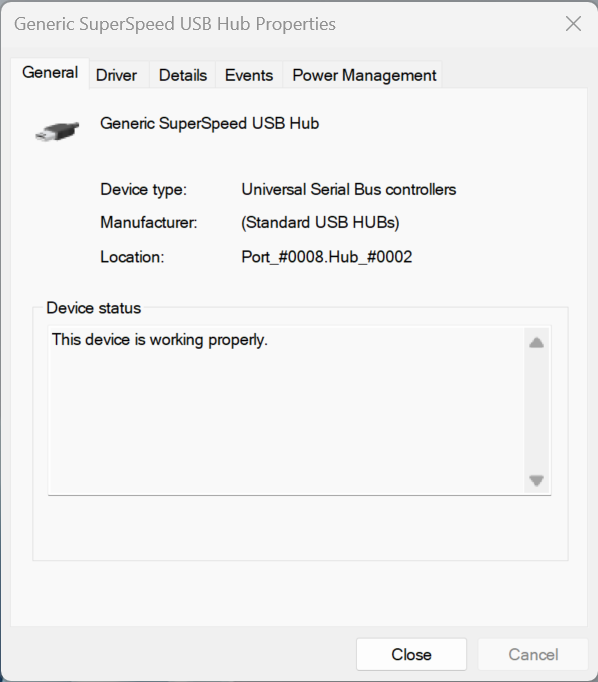
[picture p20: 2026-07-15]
Images/Bringup_DevMgr_SS_Hub_Properties.png

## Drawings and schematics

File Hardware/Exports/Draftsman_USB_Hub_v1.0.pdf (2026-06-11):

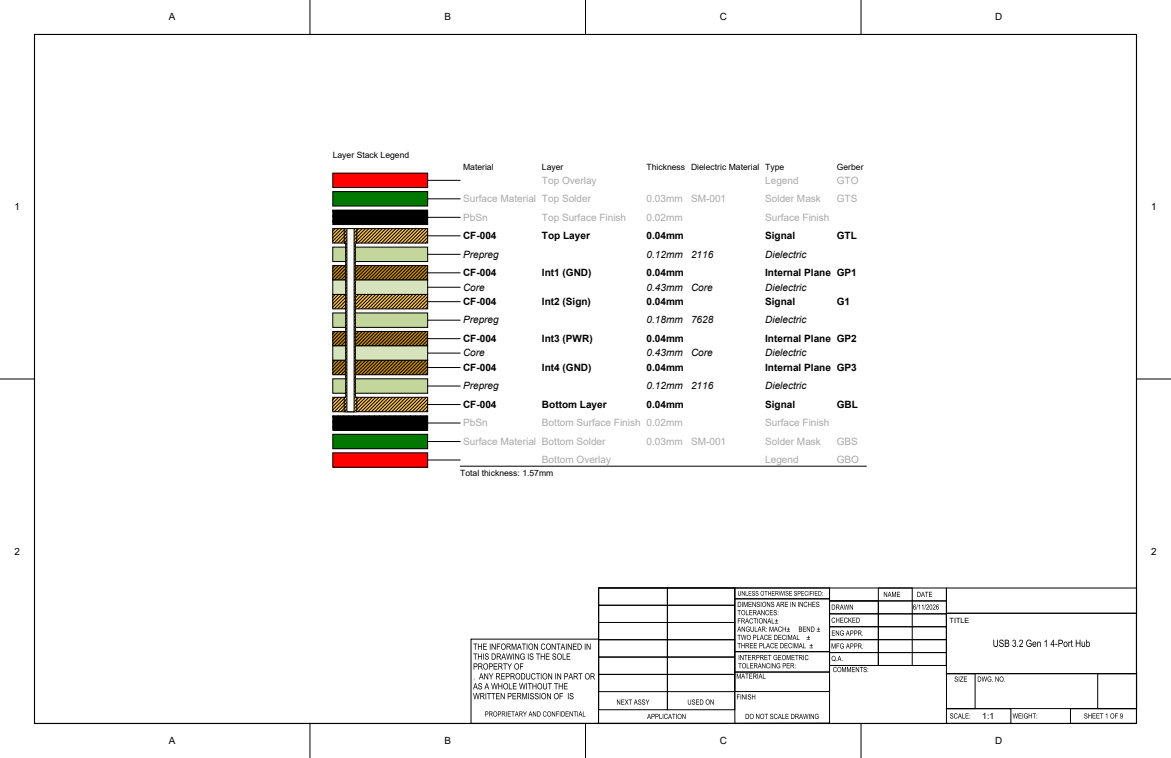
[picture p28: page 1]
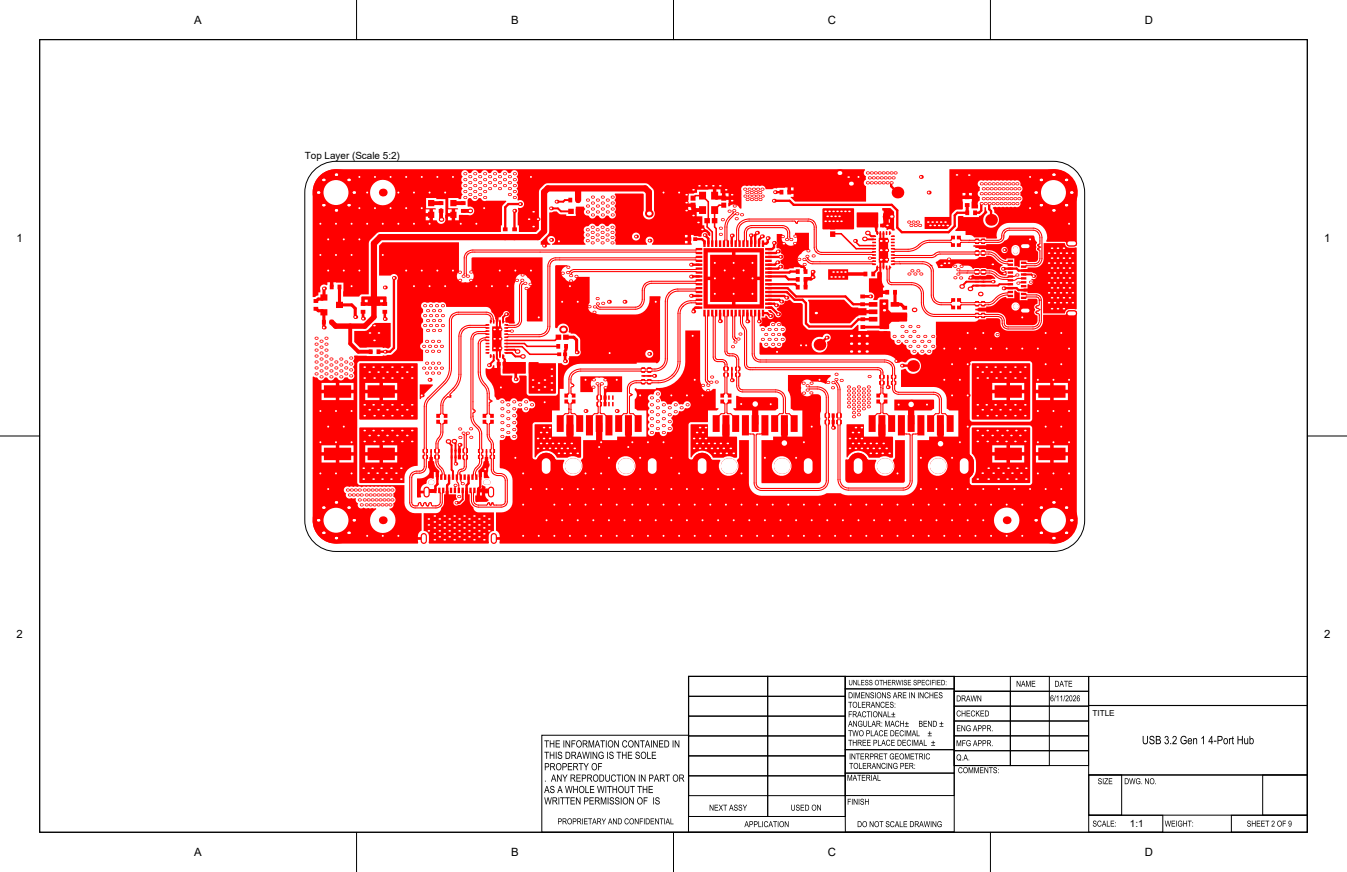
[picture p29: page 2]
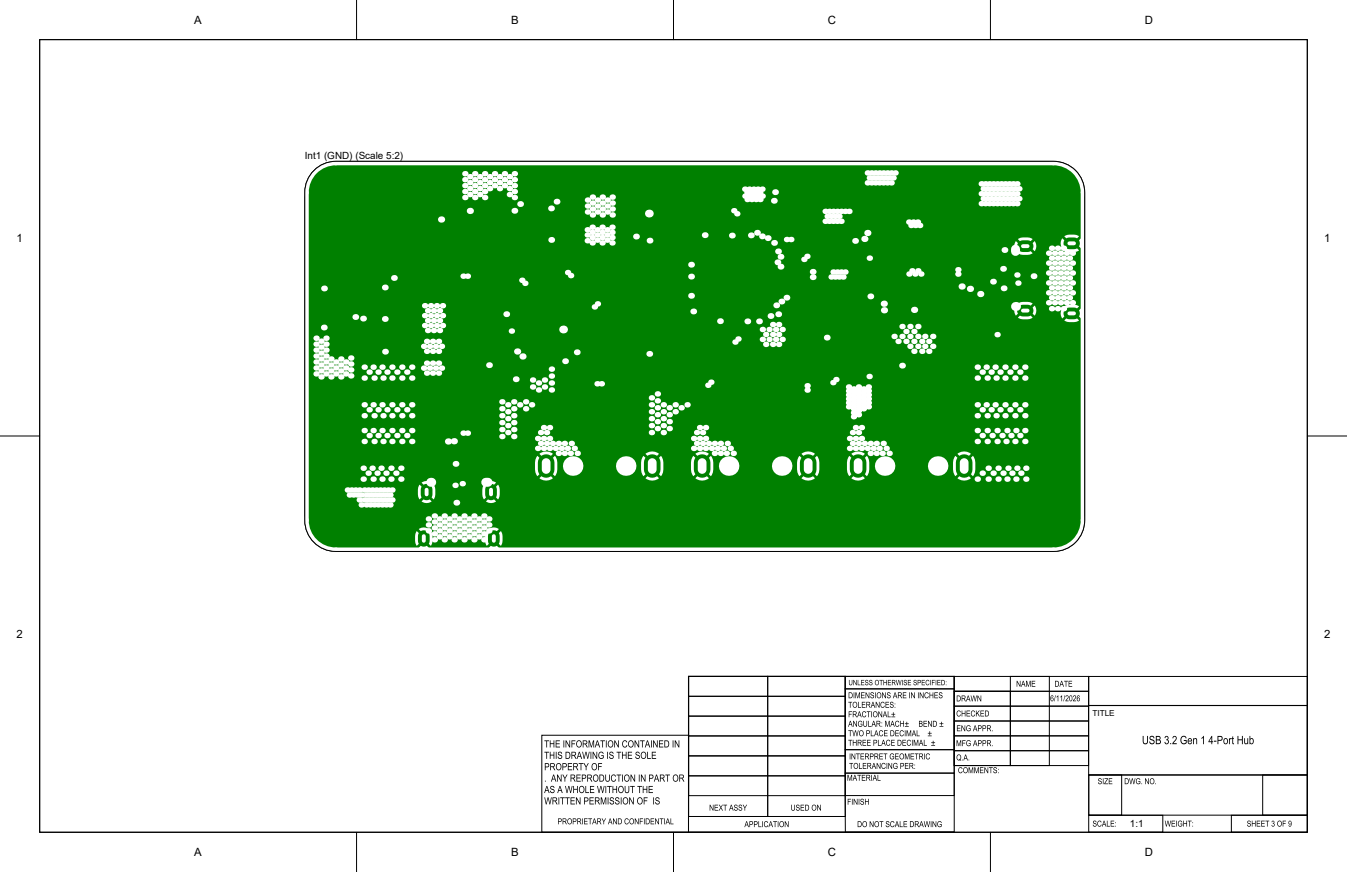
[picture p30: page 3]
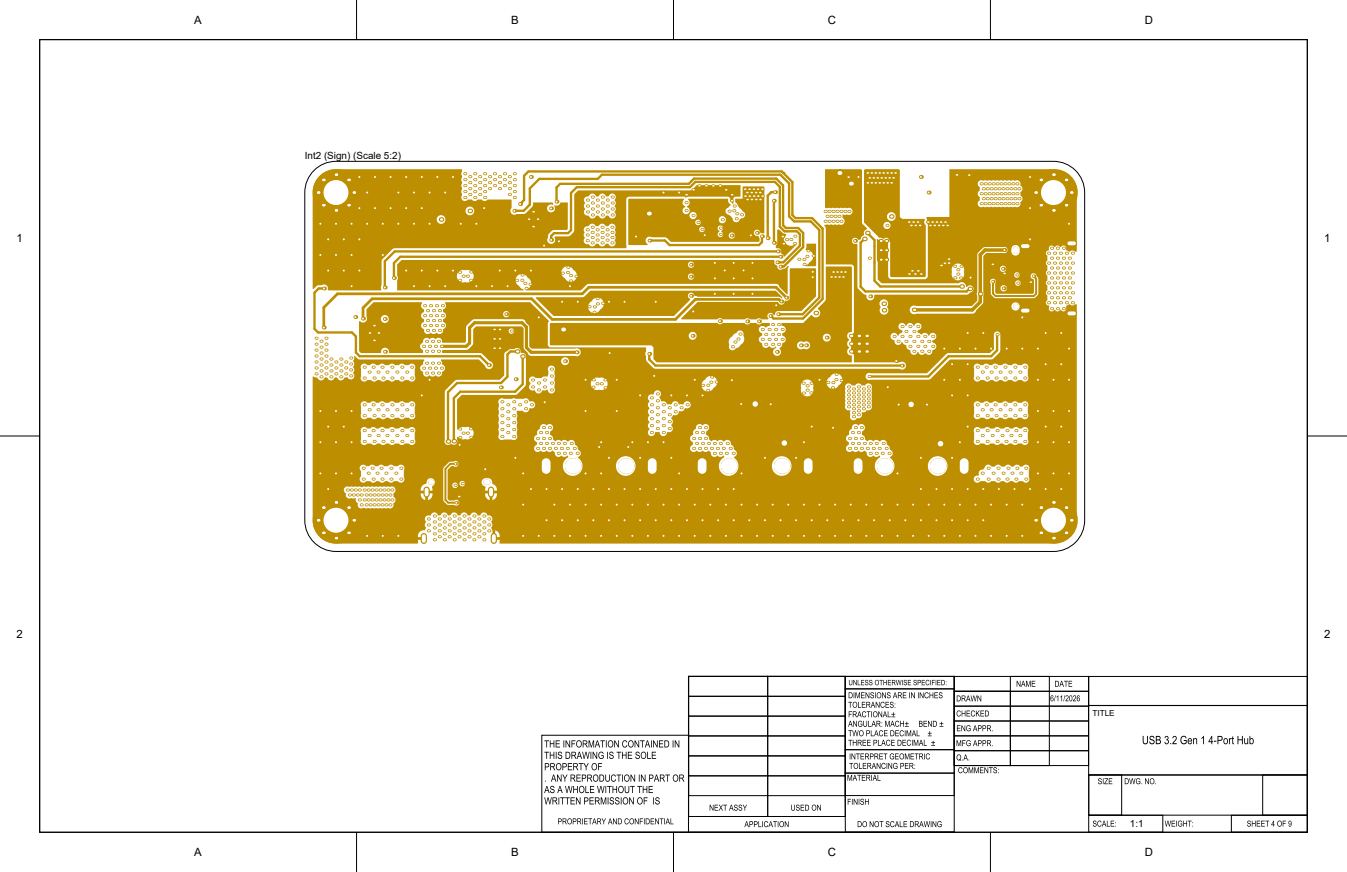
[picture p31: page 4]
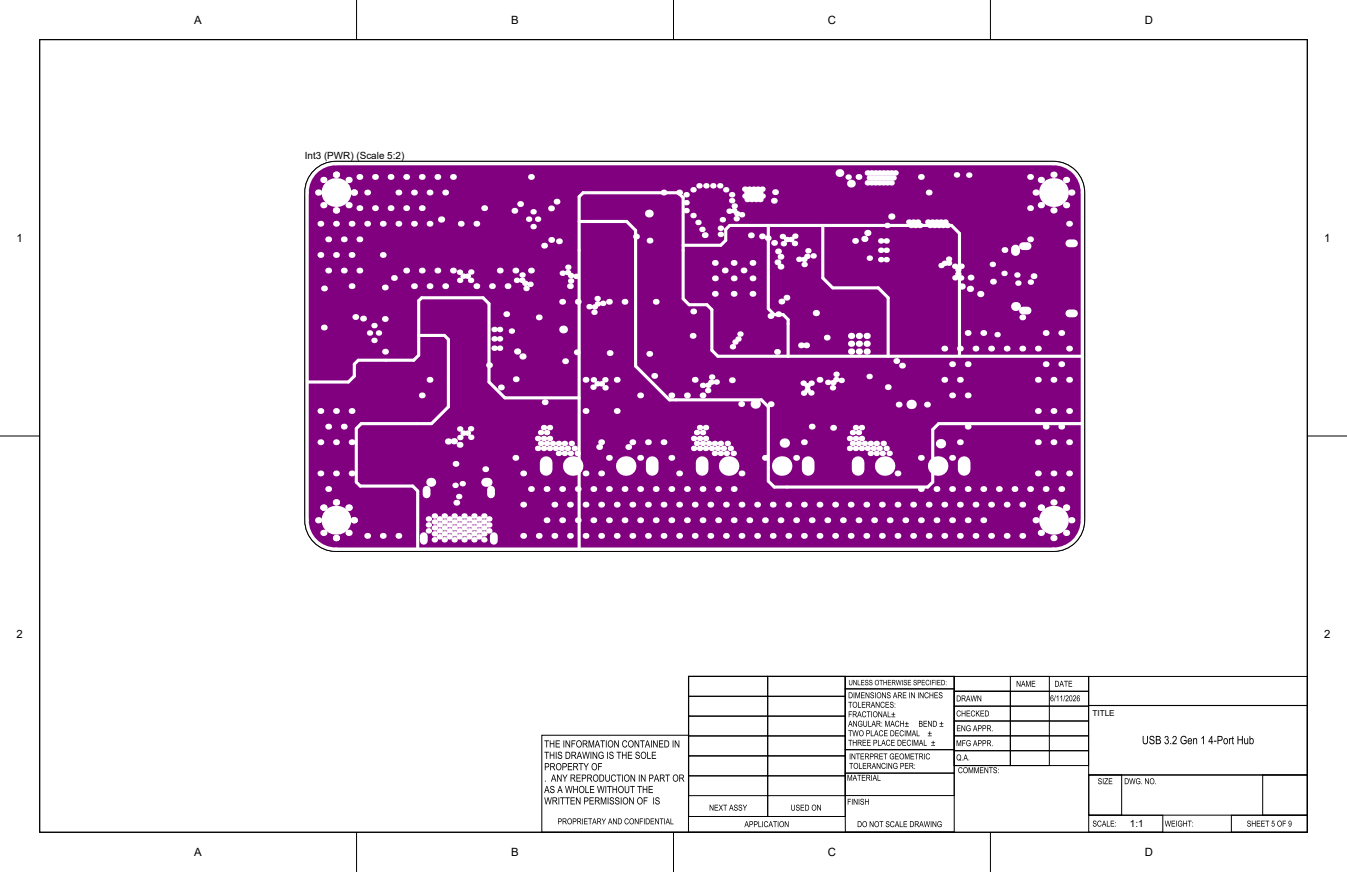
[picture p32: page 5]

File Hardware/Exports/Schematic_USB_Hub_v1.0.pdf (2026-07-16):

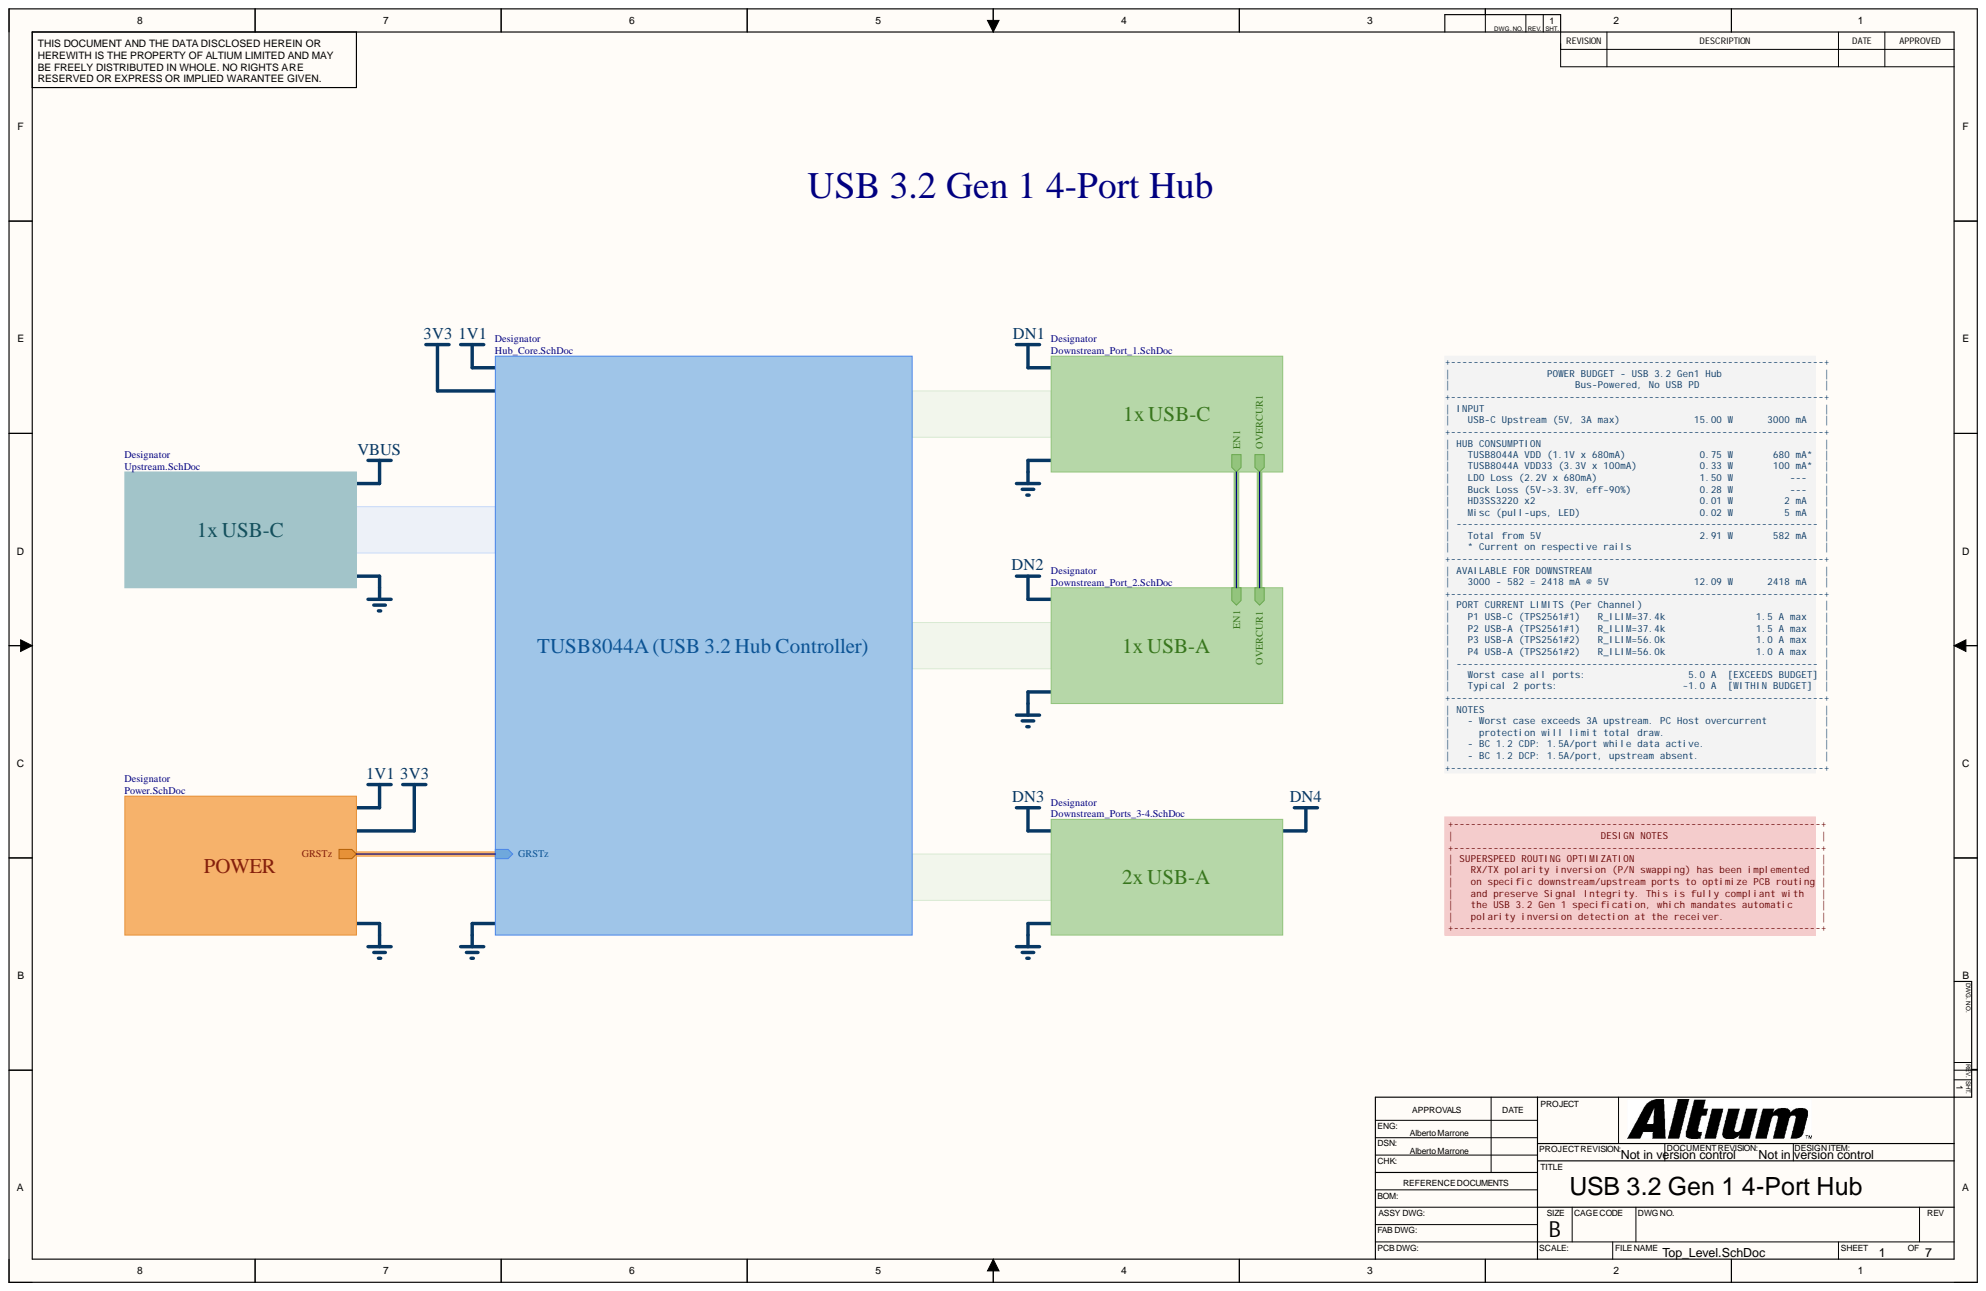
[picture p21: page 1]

THIS DOCUMENT AND THE DATA DISCLOSED HEREIN OR HEREWITH IS THE PROPERTY OF ALTIUM LIMITED AND MAY BE FREELY DISTRIBUTED IN WHOLE. NO RIGHTS ARE RESERVED OR EXPRESS OR IMPLIED WARANTEE GIVEN. | USB 3.2 Gen 1 4-Port Hub 3V3 1V1 DN1 Designator Designator | REVISION | DESCRIPTION | DATE | APPROVED

DWG. NO. | REV. | SHT.

REV. SHT. DWG. NO.

DATE | PROJECT APPROVALS

ENG: Alberto Marrone
CHK: | | TITLE USB 3.2 Gen 1 4-Port Hub

DSN: Alberto Marrone

PROJECTREVISION: | DOCUMENTREVISION: Not in version control | DESIGN ITEM: Not in version control

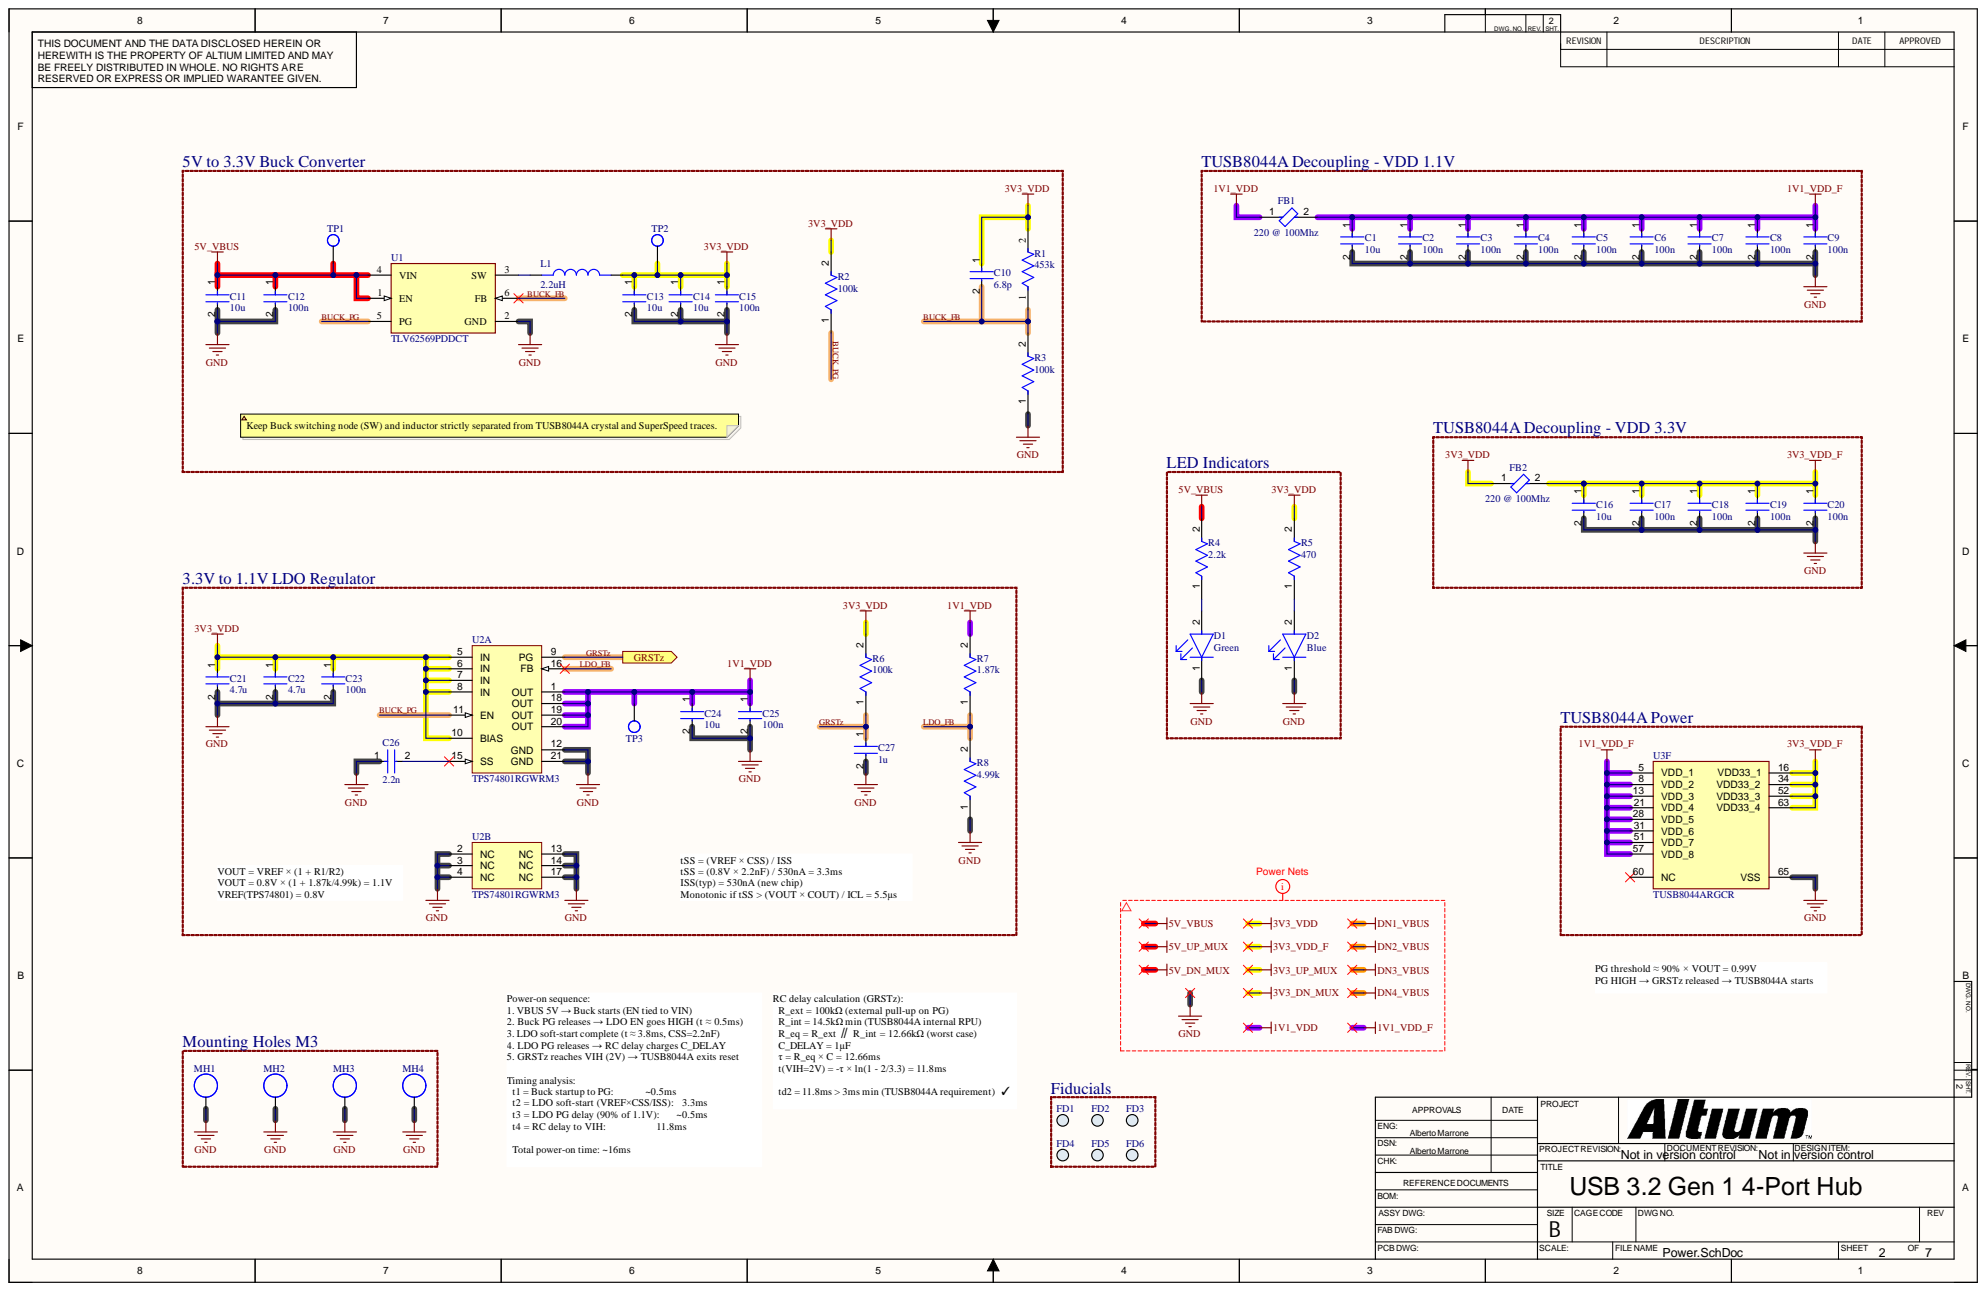
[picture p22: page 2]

BE FREELY DISTRIBUTED IN WHOLE. NO RIGHTS ARE
RESERVED OR EXPRESS OR IMPLIED WARANTEE GIVEN.

Keep Buck switching node (SW) and inductor strictly separated from TUSB8044A crystal and SuperSpeed traces.

tSS = (VREF × CSS) / ISS
tSS = (0.8V × 2.2nF) / 530nA = 3.3ms
ISS(typ) = 530nA (new chip)
Monotonic if tSS > (VOUT × COUT) / ICL = 5.5µs

PG threshold ≈ 90% × VOUT = 0.99V
PG HIGH → GRSTz released → TUSB8044A starts

REV. SHT. DWG. NO.

Power-on sequence:
1. VBUS 5V → Buck starts (EN tied to VIN)
2. Buck PG releases → LDO EN goes HIGH (t ≈ 0.5ms)
3. LDO soft-start complete (t ≈ 3.8ms, CSS=2.2nF)
4. LDO PG releases → RC delay charges C_DELAY
5. GRSTz reaches VIH (2V) → TUSB8044A exits reset

RC delay calculation (GRSTz):
R_ext = 100kΩ (external pull-up on PG)
R_int = 14.5kΩ min (TUSB8044A internal RPU)
R_eq = R_ext ∥ R_int = 12.66kΩ (worst case)
C_DELAY = 1µF
t(VIH=2V) = -τ × ln(1 - 2/3.3) = 11.8ms

Timing analysis:
t2 = LDO soft-start (VREF×CSS/ISS): 3.3ms

DATE | PROJECT APPROVALS

ENG: Alberto Marrone
CHK: | | TITLE USB 3.2 Gen 1 4-Port Hub

Total power-on time: ~16ms

DSN: Alberto Marrone

PROJECTREVISION: | DOCUMENTREVISION: Not in version control | DESIGN ITEM: Not in version control

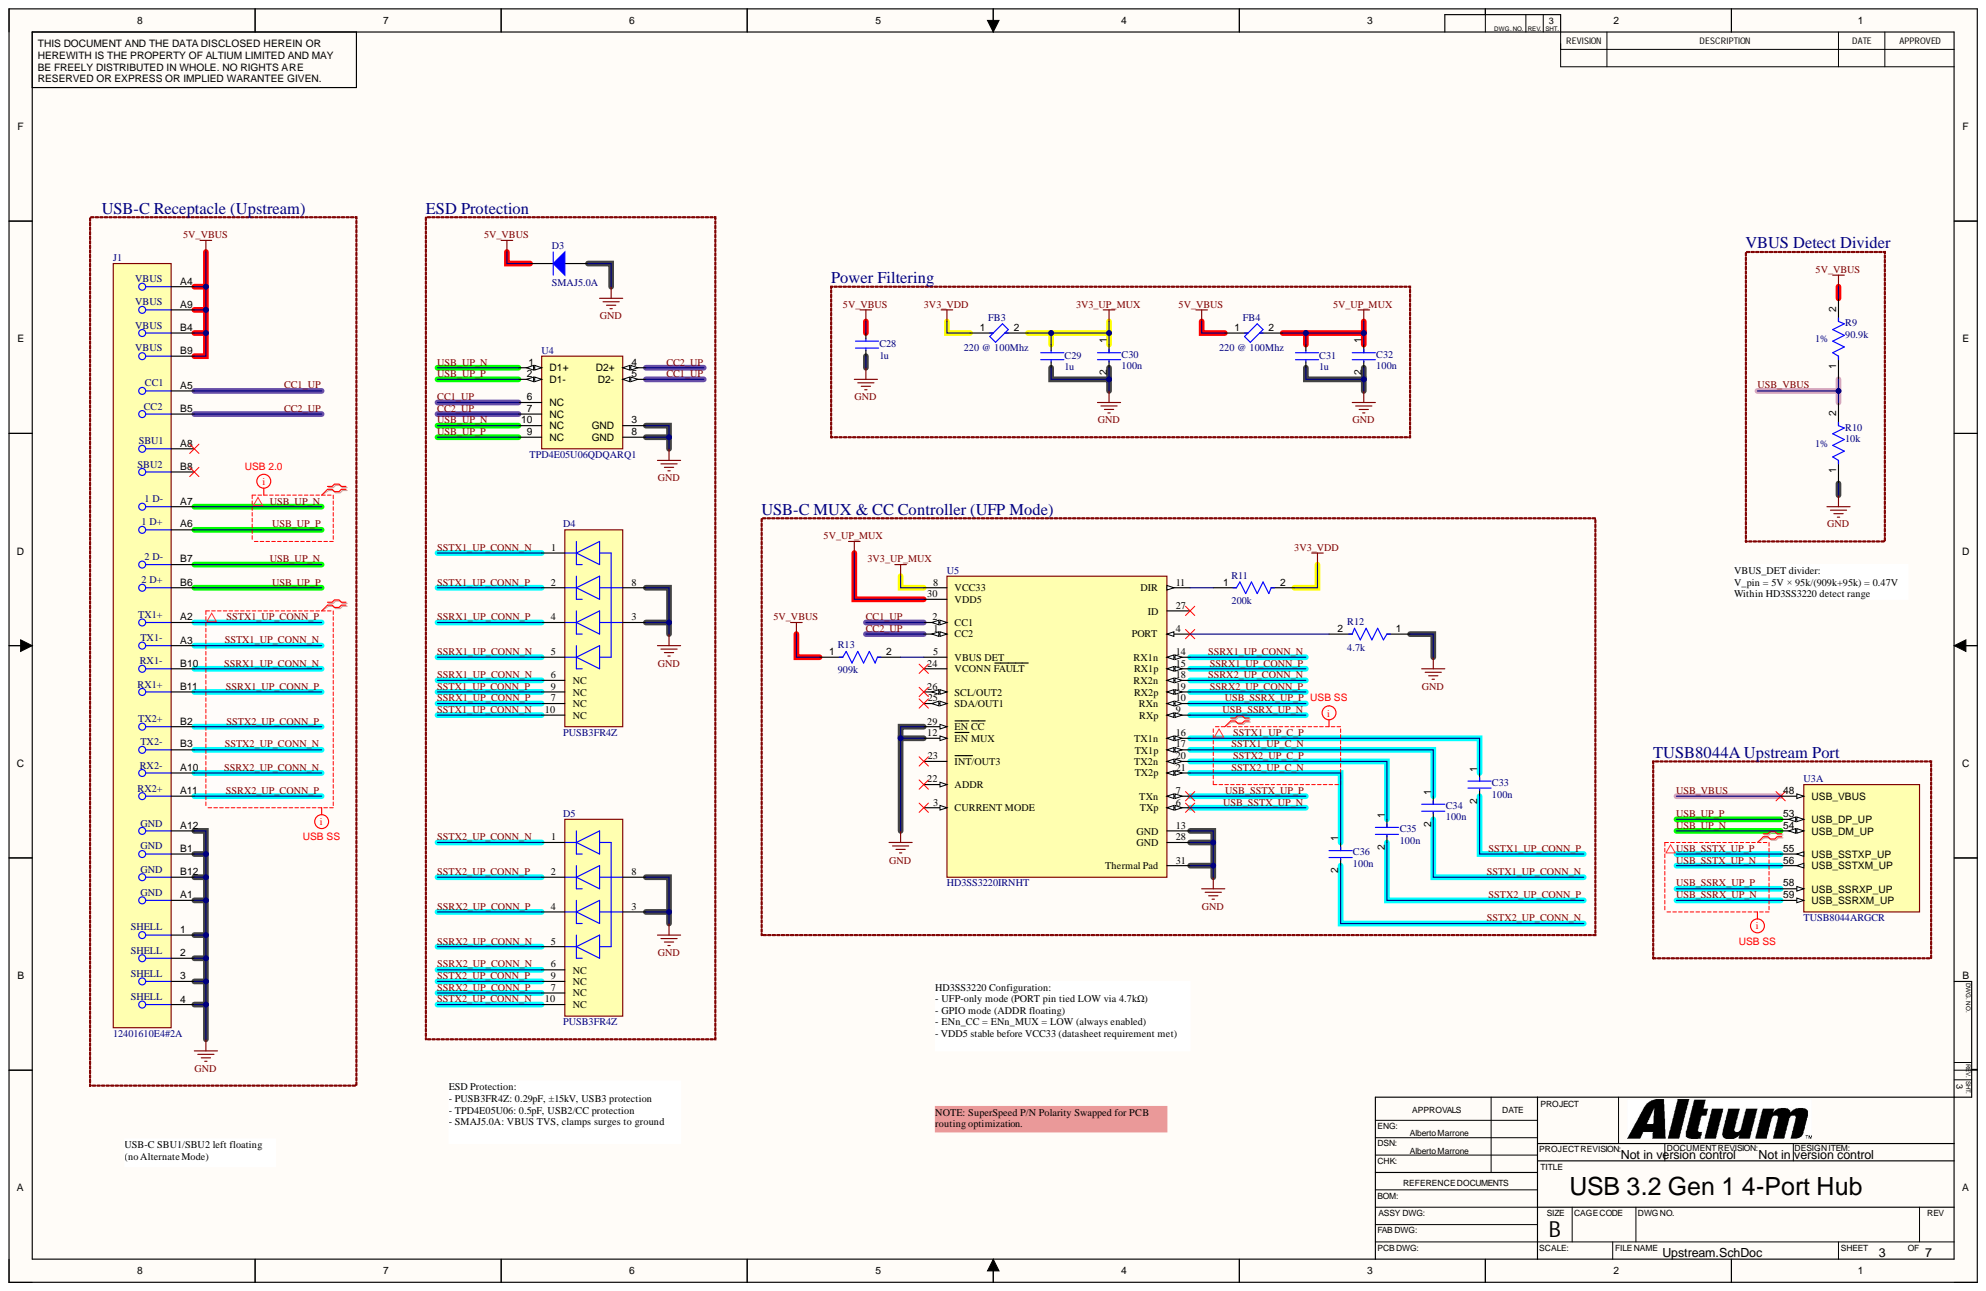
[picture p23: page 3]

THIS DOCUMENT AND THE DA TA DISCLOSED HEREIN OR HEREWITH IS THE PROPERTY OF ALTIUM LIMITED AND MA Y BE FREELY DISTRIBUTED IN WHOLE. NO RIGHTS ARE RESERVED OR EXPRESS OR IMPLIED WARANTEE GIVEN. | n 5V_VBUS | R E V I S ON | D C PTI | AT | A P OV

DW G. NO | . RE V. | SHT | .

6 | USB_SSTX_UP_N

SSTX1_UP_CONN_N

3 | | SSTX2_UP_CONN_P

HD3SS3220 Configuration
- UFP-only
- GPIO
- ENn_CC = ENn_MUX = LOW (always enabled)
- VDD5 stable before VCC33 (datasheet requiremen

REV. SHT. DWG. NO.

DATE | PR O J E CT APPROVALS

NOTE: SuperSpeed P/N Polarity Swapped for PCB
rou

EN G : Al b ert o M arro n e

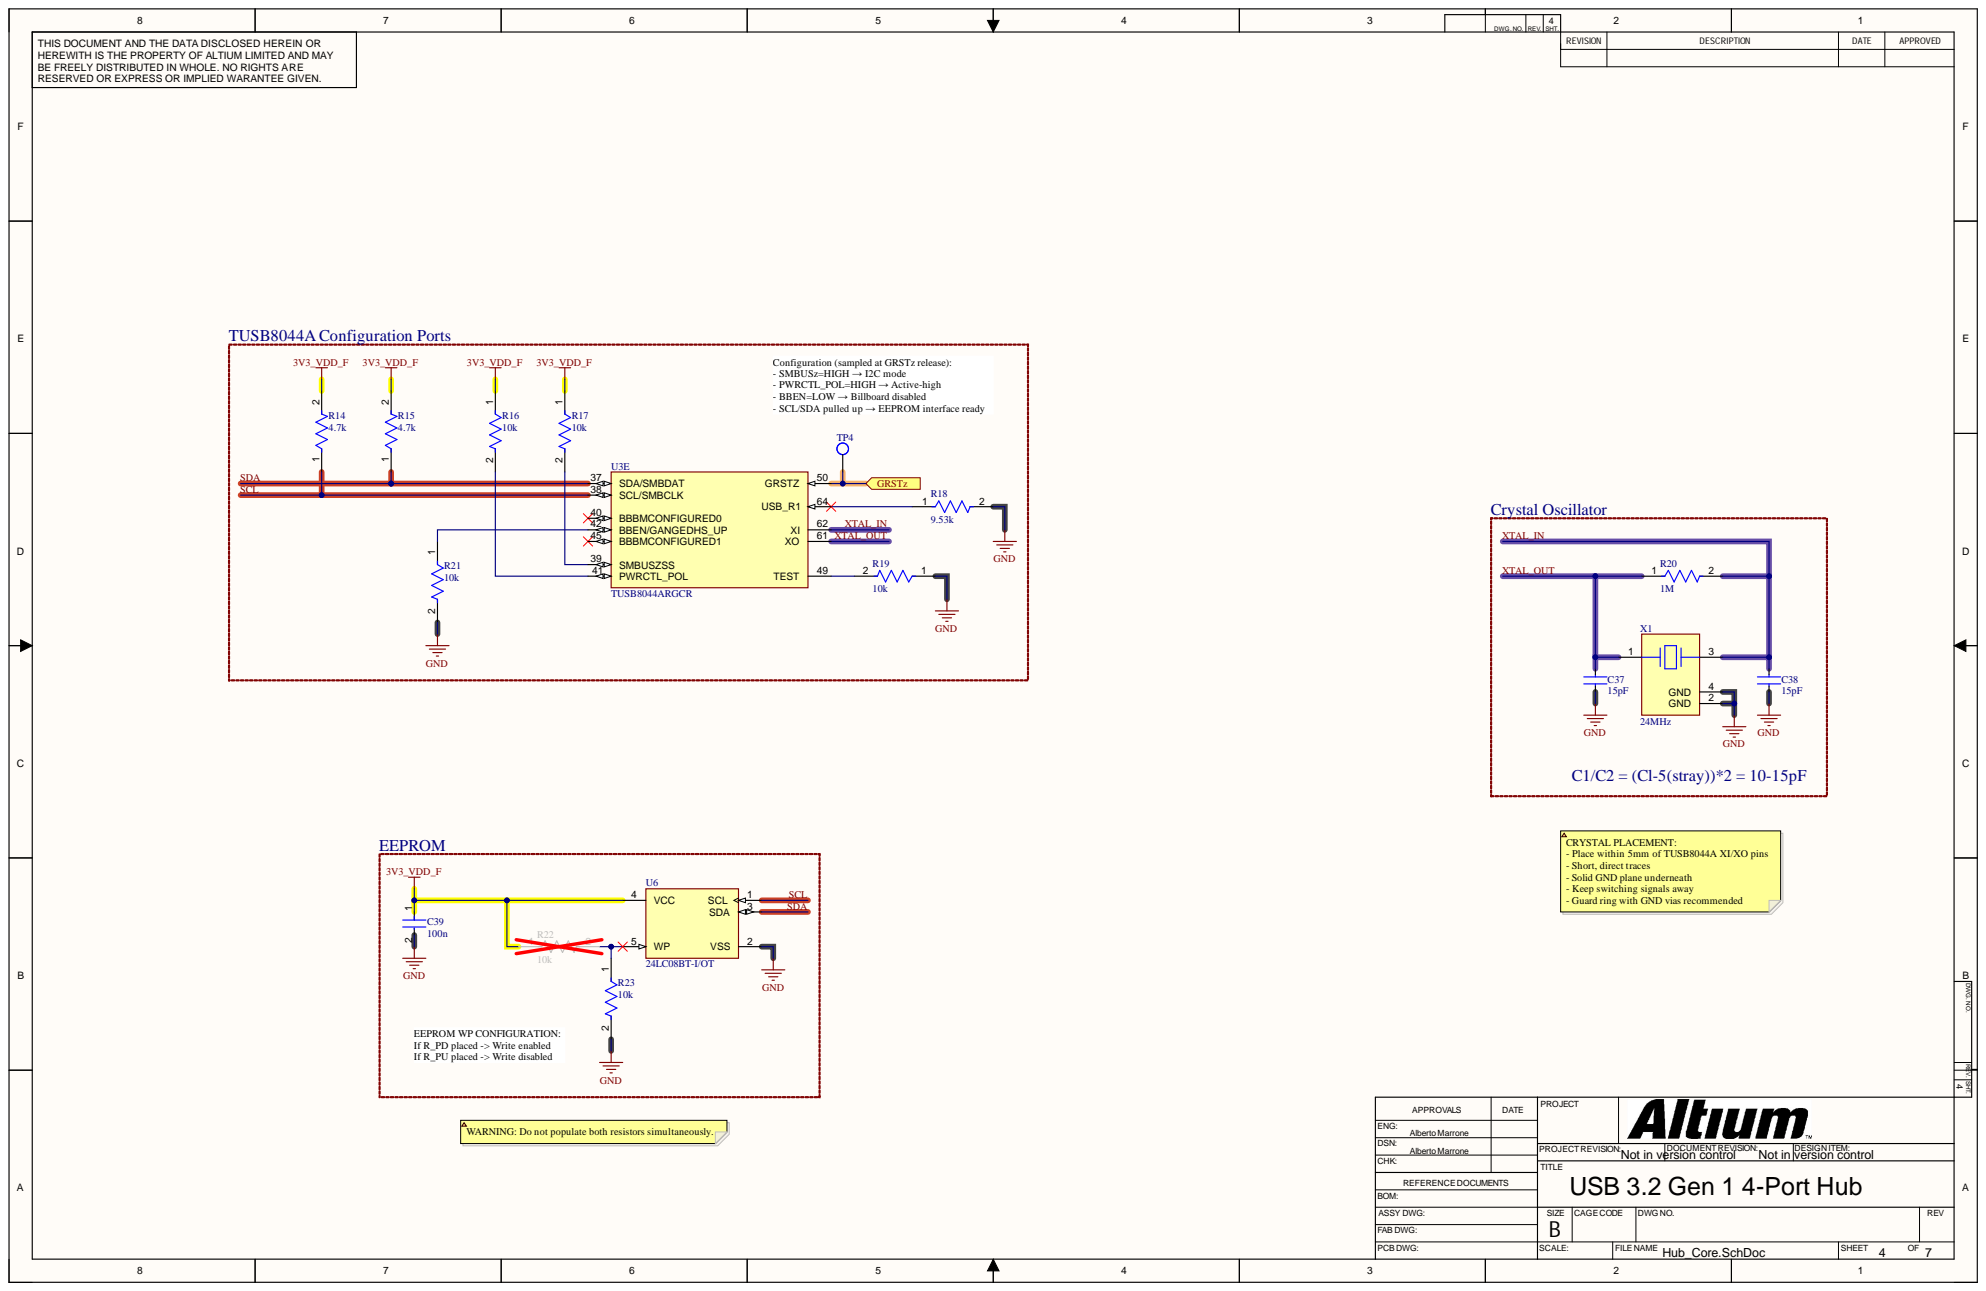
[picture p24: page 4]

BE FREELY DISTRIBUTED IN WHOLE. NO RIGHTS ARE
RESERVED OR EXPRESS OR IMPLIED WARANTEE GIVEN.

Configuration (sampled at GRSTz release):
- SMBUSz=HIGH
- PWRCTL_POL=HIGH
- BBEN=LOW
- SCL/SDA pulled

CRYSTAL PLACEMENT
- Place wit
- Short
- Solid GND plane
- Keep switching signals away
- Guard ring wit

REV. SHT. DWG. NO.

DATE | PR O J E CT APPROVALS

EN G : Al b ert o M arro n e
C H K : | | T I T L E USB 3.2 Ge n 1 4-Port Hu b

DSN : Al b ert o M arro n e

PR O JEC T REVI S I O N : | D O C U MEN T REVI S I O N : Not in version co | DESI G N I T E M : Not in version control ntr o l

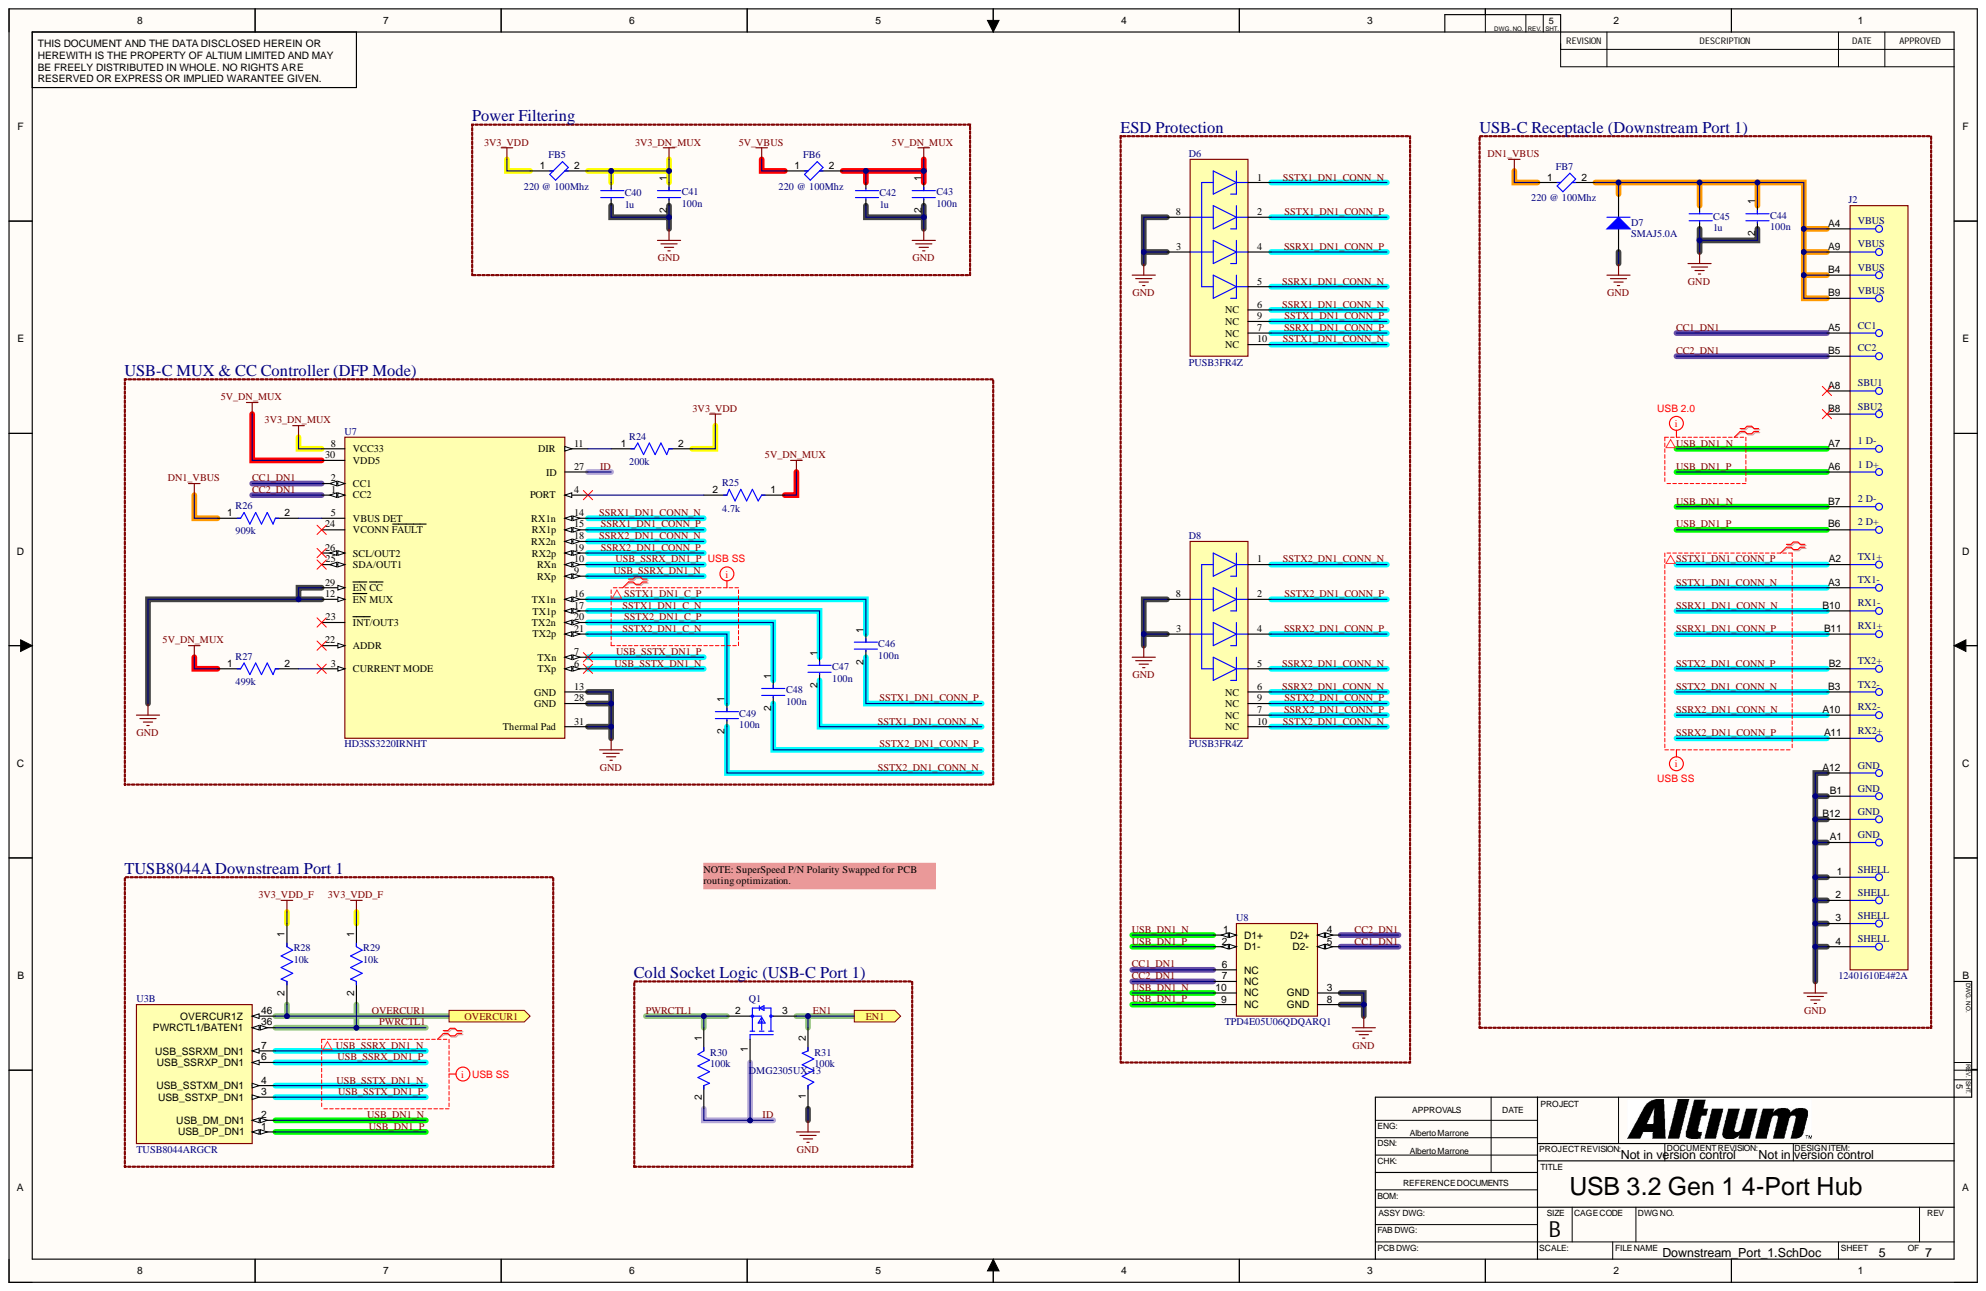
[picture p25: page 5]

BE FREELY DISTRIBUTED IN WHOLE. NO RIGHTS ARE
RESERVED OR EXPRESS OR IMPLIED WARANTEE GIVEN.

USB-C MUX & CC Controller (DFP Mode)

SSTX1_DN1_CONN_P

SSTX1_DN1_CONN_N

SSTX2_DN1_CONN_P

NOTE: SuperSpeed P/N Polarity Swapped for PCB
routing optimization.

Cold Socket Logic (USB-C Port 1)

REV. SHT. DWG. NO.

DATE | PROJECT APPROVALS

ENG: Alberto Marrone

USB 3.2 Gen 1 4-Port Hub

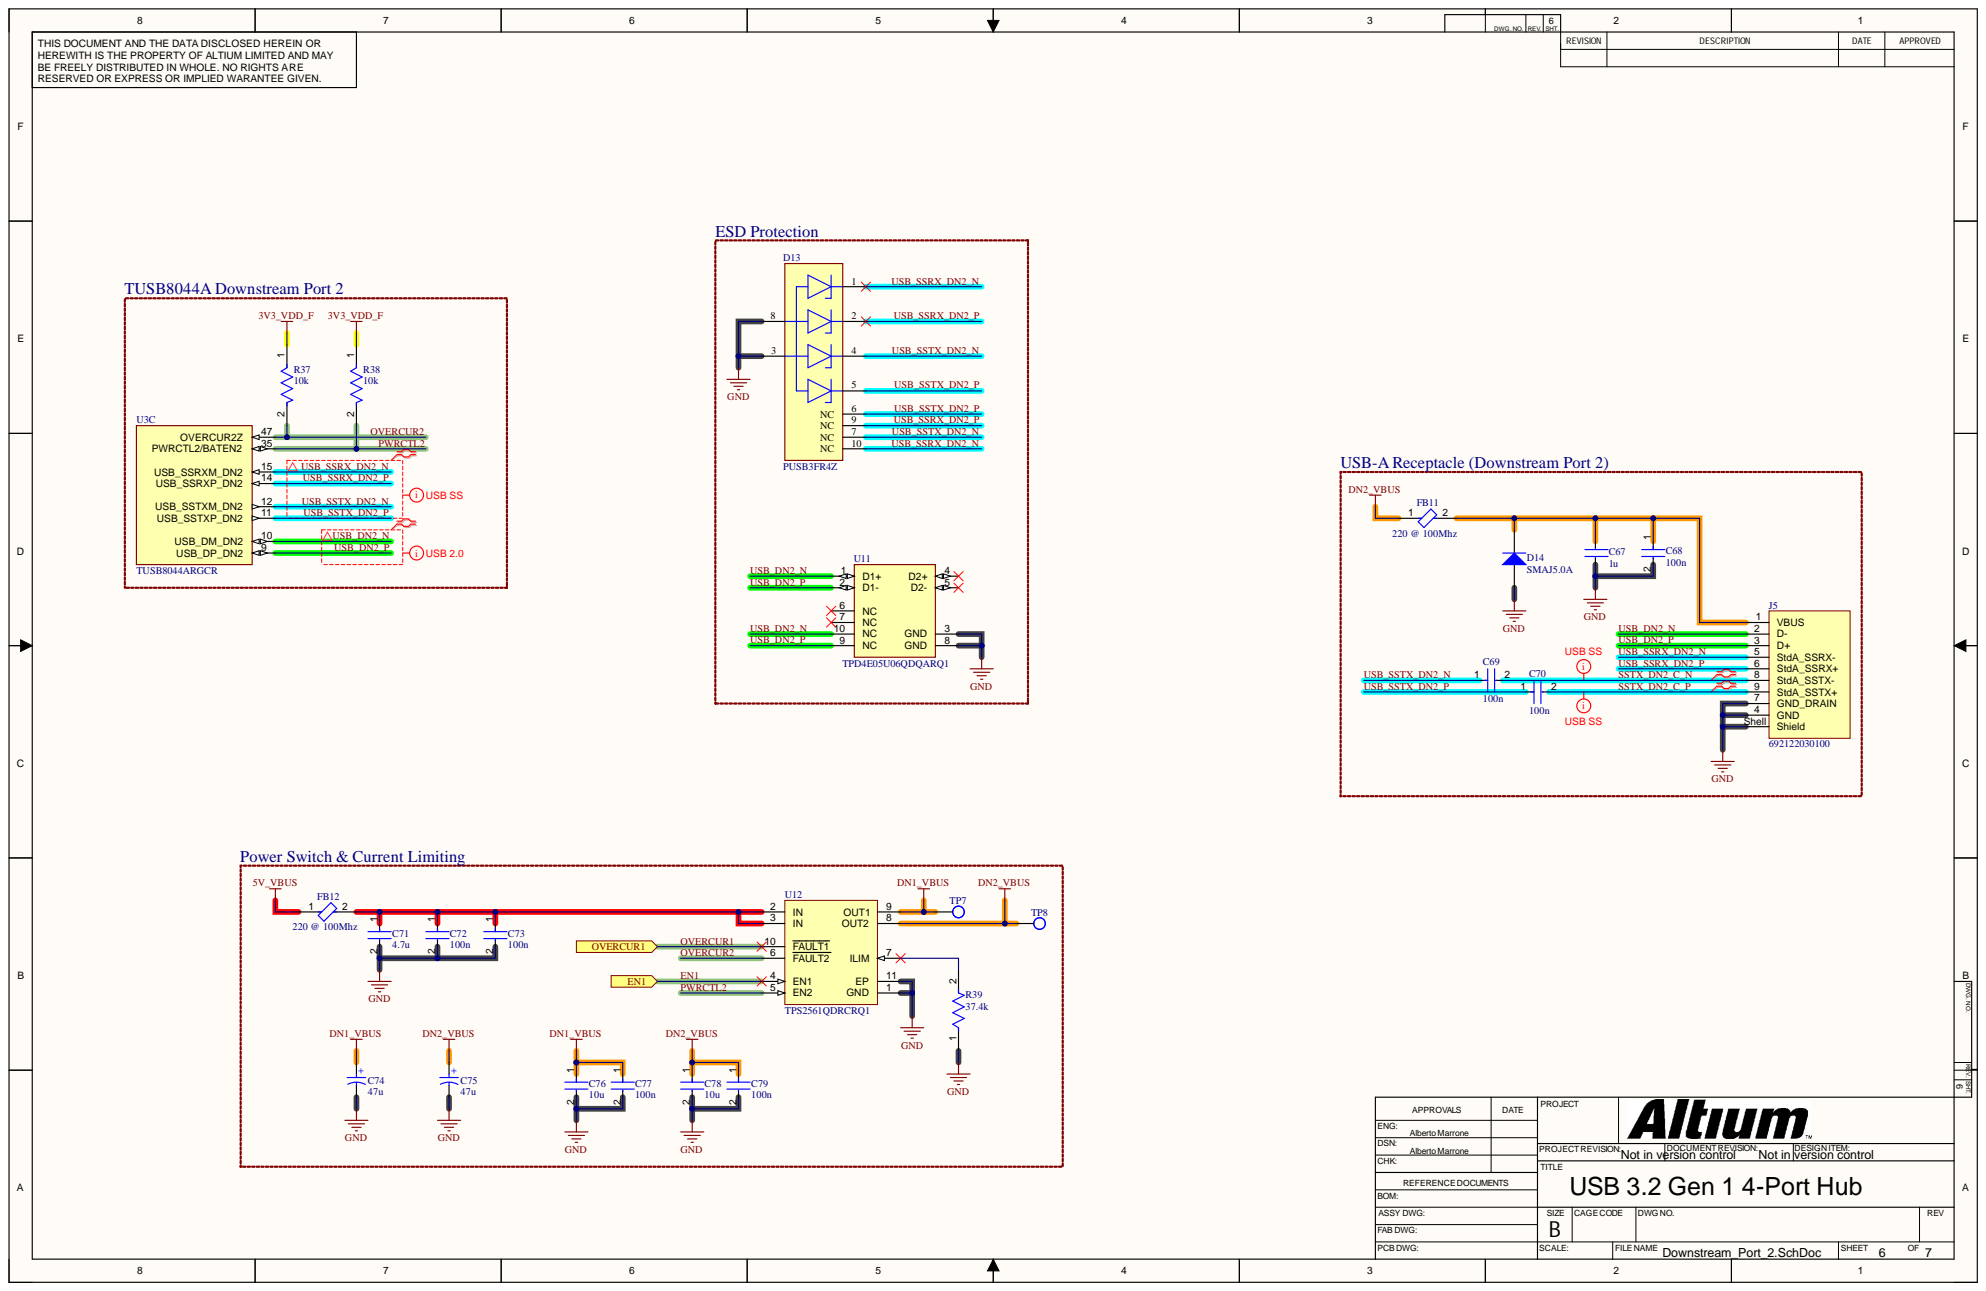
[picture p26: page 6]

BE FREELY DISTRIBUTED IN WHOLE. NO RIGHTS ARE
RESERVED OR EXPRESS OR IMPLIED WARANTEE GIVEN.

USB-A Receptacle (Downstream Port 2)

Power Switch & Current Limiting

REV. SHT. DWG. NO.

DSN: Alberto Marrone
CHK: | | TITLE USB 3.2 Gen 1 4-Port Hub

PROJECTREVISION: | DOCUMENTREVISION: Not in version control | DESIGN ITEM: Not in version control

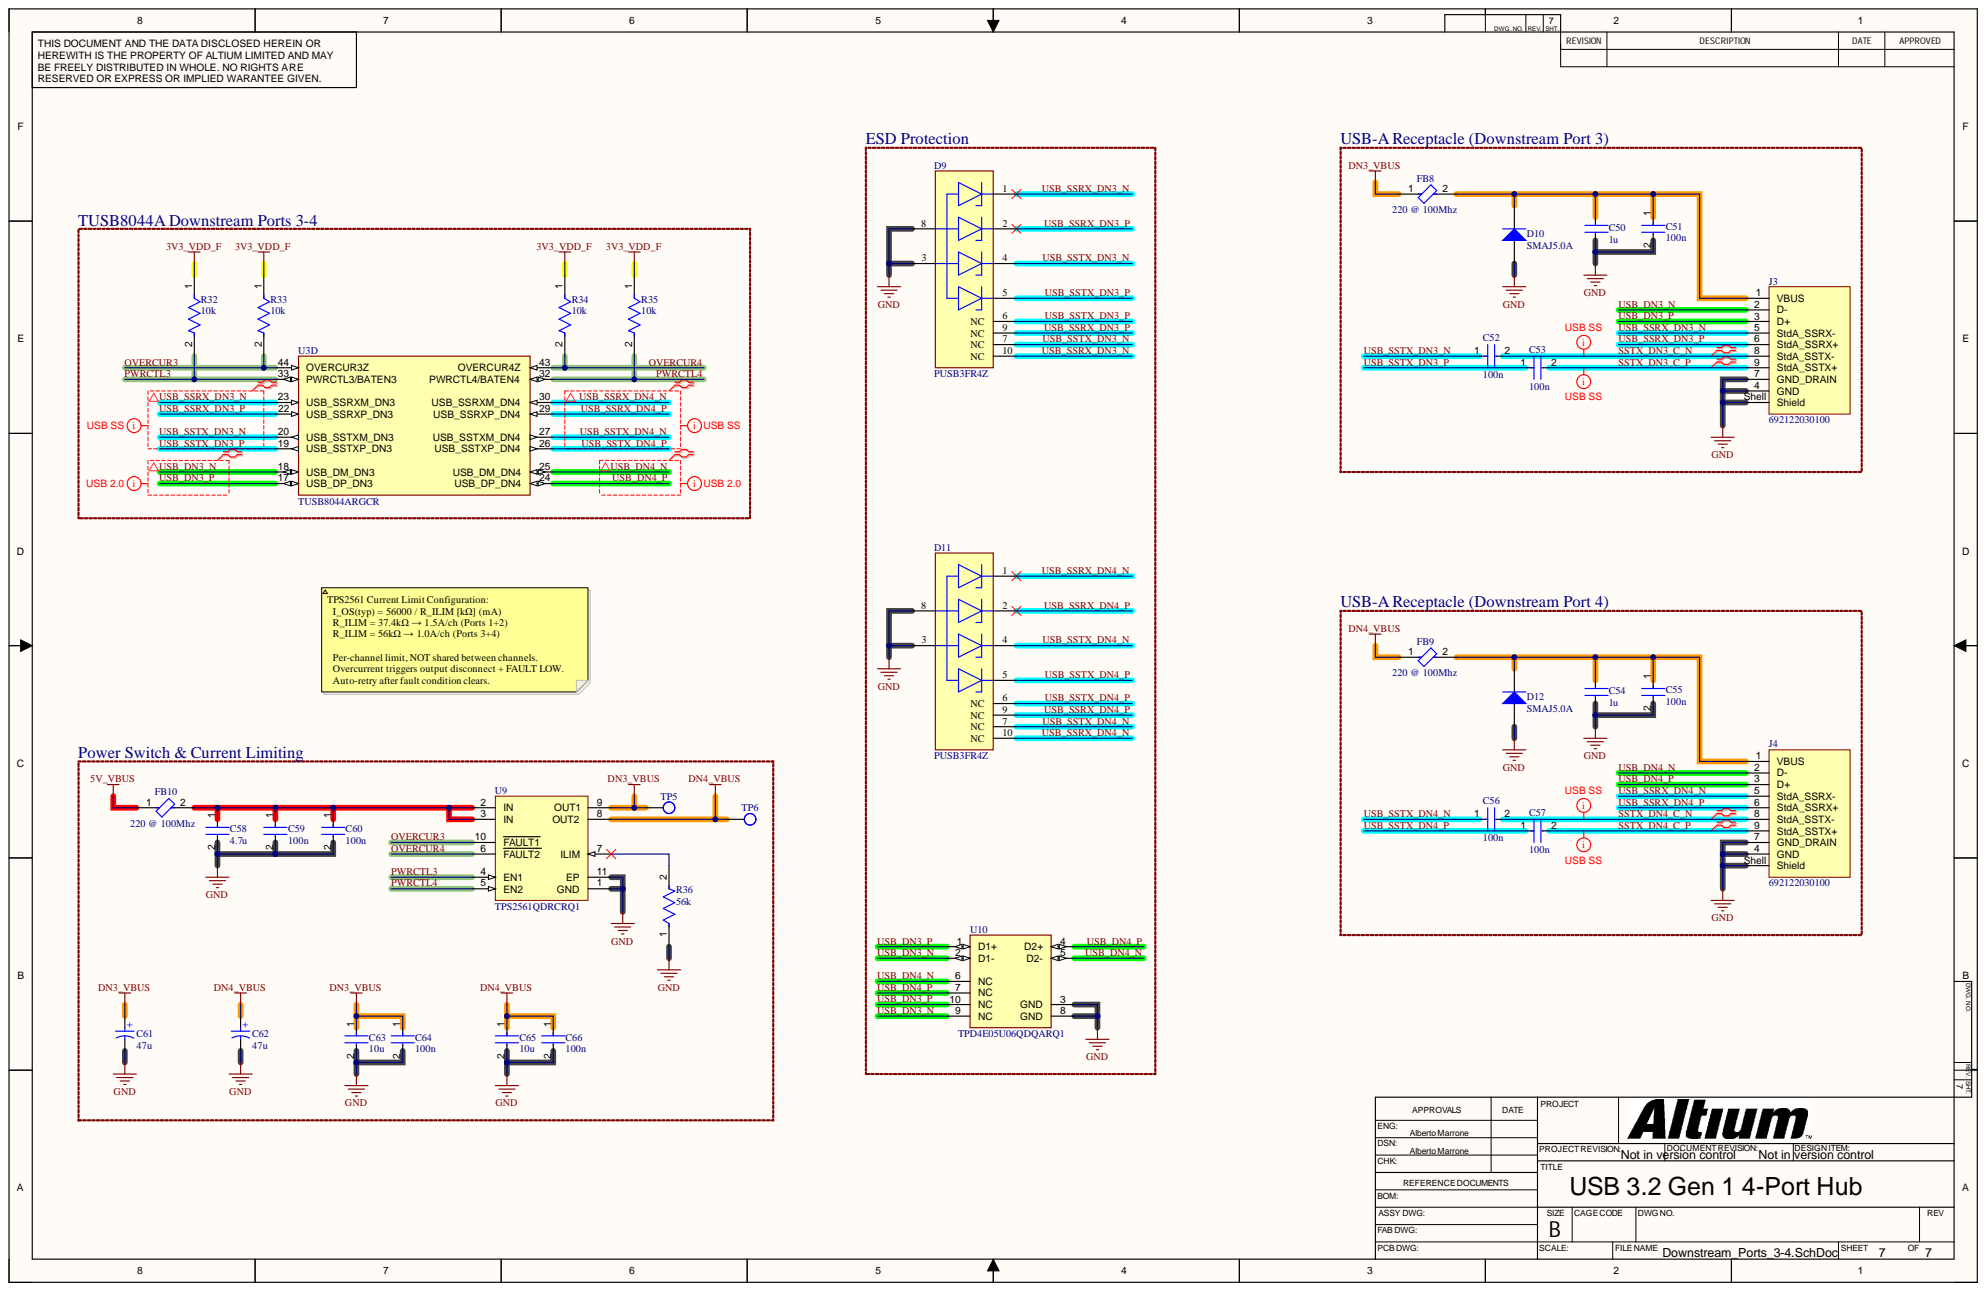
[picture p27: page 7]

BE FREELY DISTRIBUTED IN WHOLE. NO RIGHTS ARE
RESERVED OR EXPRESS OR IMPLIED WARANTEE GIVEN.

, NOT shared between chan
triggers ou

to-retry after fault condition clears.

REV. SHT. DWG. NO.

DATE | PR O J E CT APPROVALS

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

DSN : Al b ert o M arro n e

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
